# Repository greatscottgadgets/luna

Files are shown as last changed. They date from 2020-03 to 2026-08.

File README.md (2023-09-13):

# LUNA: an Amaranth HDL library for USB  

LUNA is a toolkit for working with USB using FPGA technology, providing gateware and software to enable USB applications.

Some things you can use LUNA for, currently:

- **Protocol analysis for Low-, Full-, or High- speed USB.** LUNA provides gateware that allow passive USB monitoring when combined with [Cynthion](https://github.com/greatscottgadgets/cynthion-hardware) and [Packetry](https://github.com/greatscottgadgets/packetry).
- **Creating your own Low-, Full-, High-, or (experimentally) Super- speed USB device.** LUNA provides a collection of Amaranth gateware that allows you to easily create USB devices in gateware, software, or a combination of the two.
- **Building USB functionality into a new or existing System-on-a-Chip (SoC).** LUNA is capable of generating custom peripherals targeting the common Wishbone bus; allowing it to easily be integrated into SoC designs; and the [luna-soc](https://github.com/greatscottgadgets/luna-soc) library provides simple automation for developing simple SoC designs.

Some things you'll be able to use LUNA for in the future:

- **Man-in-the-middle'ing USB communications.** The LUNA toolkit will be able to act
  as a *USB proxy*, transparently modifying USB data as it flows between a host and a device.
- **USB reverse engineering and security research.** The LUNA toolkit will serve as an ideal
  backend for tools like [Facedancer](https://github.com/usb-tools/facedancer); allowing easy
  emulation and rapid prototyping of compliant and non-compliant USB devices.

## Project Structure

This project is broken down into several directories:

* `luna` -- the primary LUNA python toolkit; generates gateware and provides USB functionality
  * `luna/gateware` -- the core gateware components for LUNA; and utilities for stitching them together
* `examples` -- simple LUNA-related examples; mostly gateware-targeted, currently
* `docs` -- sources for the LUNA Sphinx documentation
* `contrib` -- contributed/non-core components; such as udev rules
* `applets` -- pre-made gateware applications that provide useful functionality on their own (e.g., are more than examples)

## Project Documentation

LUNA's documentation is captured on [Read the Docs](https://luna.readthedocs.io/en/latest/). Raw documentation sources
are in the `docs` folder.

## Related Projects

* [Cynthion](https://github.com/greatscottgadgets/cynthion-hardware): an open source hardware USB test instrument
* [Apollo](https://github.com/greatscottgadgets/apollo): the firmware that runs on Cynthion's debug controller and which is responsible for configuring its FPGA
* [Saturn-V](https://github.com/greatscottgadgets/saturn-v): a DFU bootloader created for Cynthion
* [Packetry](https://github.com/greatscottgadgets/packetry): software for USB analysis
* [Facedancer](https://github.com/greatscottgadgets/facedancer): software to create USB devices in Python

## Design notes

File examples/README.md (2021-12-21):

# LUNA Examples

This folder contains simple example projects for LUNA, both for using LUNA as a specialized FPGA board, and for using the LUNA framework.

Included;

 * `blinky_verilog`: Simple example of how to program a LUNA board in Verilog.
 * `blinky`: A more standard blinky example, in Amaranth HDL.

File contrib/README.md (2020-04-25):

# Misc / 'Contributed' Files

This folder contains files that are not supported as part of the core LUNA project, but which may be useful to users anyway.

Contents:

 - `54-luna-uaccess.rules` -- _udev_ rules that grant users physically present at a machine access to LUNA devices. Recommended for most desktop Linux users.
 - `54-luna-plugdev.rules` -- _udev_ rules that grant users in the `plugdev` group access to LUNA devices. Recommended for systems where you'll be acccessing the toolsremotely; e.g. via SSH.

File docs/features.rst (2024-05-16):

================
Status & Support
================

.. role:: planned
.. role:: inprogress
.. role:: needstest
.. role:: complete

The LUNA library is a work in progress; but many of its features are usable enough for inclusion in your own designs.
More testing of our work -- and more feedback -- is always appreciated!

Support for Device Mode
-----------------------

.. list-table::
    :header-rows: 1
    :widths: 1 2 1

    * - Feature
      -
      - Status
    * - **USB Communications**
      - high-/full-speed with ``UTMI`` PHY
      - :needstest:`complete, needs testing`
    * -
      - high-/full-speed with ``ULPI`` PHY
      - :complete:`feature complete`
    * -
      - full-speed using raw gpio / pull resistors
      - :complete:`feature complete`
    * -
      - super-speed using PIPE PHY
      - :needstest:`basic support complete; still experimental`
    * -
      - super-speed using SerDes PHY
      - :inprogress:`in progress`
    * -
      - low speed, via ULPI/UTMI PHY
      - :planned:`untested`
    * -
      - low speed, using raw gpio / pull resistors
      - :planned:`unsupported, currently`
    * -
      -
      -
    * - **Control Transfers / Endpoints**
      - user-defined
      - :complete:`feature complete`
    * -
      - fully-gateware-implemented, with user vendor request handler support
      - :needstest:`complete, could use improvements`
    * -
      - CPU interface
      - :inprogress:`working; needs more interfaces & examples`
    * -
      -
      -
    * - **Bulk Transfers / Endpoints**
      - user-defined
      - :complete:`feature complete`
    * -
      - ``IN`` stream helpers
      - :complete:`feature complete`
    * -
      - ``OUT`` stream helpers
      - :complete:`feature complete`
    * -
      - CPU interface
      - :inprogress:`working; needs more interfaces & examples`
    * -
      -
      -
    * - **Interrupt Transfers / Endpoints**
      - user-defined
      - :complete:`feature complete`
    * -
      - status-to-host helper
      - :needstest:`complete, needs testing`
    * -
      - status-from-host helper
      - :planned:`planned`
    * -
      - CPU interface
      - :inprogress:`working; needs more interfaces & examples`
    * -
      -
      -
    * - **Isochronous Transfers / Endpoints**
      - user-defined
      - :planned:`planned`
    * -
      - ``IN`` transfer helpers
      - :needstest:`complete; needs examples and testing`
    * -
      - ``OUT`` transfer helpers
      - :planned:`planned`
    * -
      - CPU interface
      - :planned:`planned`
    * -
      -
      -
    * - **USB Analysis**
      - basic analysis
      - :inprogress:`basic analysis working, in progress`
    * -
      - full analysis support
      - :planned:`planned`

Support for Host Mode
-----------------------

The LUNA library currently does not provide any support for operating as a USB host; though the low-level USB
communications interfaces have been designed to allow for eventual host support. Host support is not currently
a priority, but contributions are welcome.

"Reference" Boards
------------------

The LUNA library is intended to work on any FPGA with sufficient fabric performance and resources; but testing is
only performed on a collection of reference boards.

.. list-table::
    :header-rows: 1
    :widths: 4 2 2 2

    * - Board
      - FPGA Family
      - PHY
      - Status
    * - `Cynthion <https://greatscottgadgets.com/cynthion/>`__
      - ECP5
      - ULPI x3 (USB3343)
      - :complete:`Fully Supported`
    * - OpenVizsla USB Analyzer
      - Spartan 6
      - ULPI (USB3343)
      - :complete:`Fully Supported`
    * - LambdaConcept ECPIX-5
      - ECP5
      - ULPI (USB3300), SerDes PHY
      - :complete:`High-Speed Fully Supported` / :inprogress:`Super-Speed In Progress`
    * - TinyFPGA Ex
      - ECP5
      - SerDes PHY
      - :planned:`Planned Super-Speed Device Mode`
    * - Logicbone
      - ECP5
      - SerDes PHY
      - :complete:`Full-Speed Fully Supported` / :inprogress:`Super-Speed In Progress`
    * - Daisho
      - Cyclone IV
      - PIPE (TUSB1310A)
      - :planned:`Planned Super-Speed Device Mode`
    * - PHYWhisperer-USB
      - Spartan 7
      - UTMI
      - :planned:`Planned Device Mode Support`
    * - LambdaConcept USB2Sniffer
      - Artix 7
      - ULPI x2 (USB3300)
      - :complete:`Fully Supported`
    * - OrangeCrab
      - ECP5
      - no hardware PHY
      - :complete:`Full-Speed/Device Mode Support`
    * - ULX3S
      - ECP5
      - no hardware PHY
      - :complete:`Full-Speed/Device Mode Support`
    * - Fomu PVT/Hacker
      - iCE40 UP
      - no hardware PHY
      - :complete:`Full-Speed/Device Mode Support`
    * - Fomu EVT3
      - iCE40 UP
      - no hardware PHY
      - :complete:`Full-Speed/Device Mode Support`
    * - iCEBreaker Bitsy
      - iCE40 UP
      - no hardware PHY
      - :complete:`Full-Speed/Device Mode Support`
    * - Glasgow
      - iCE40 HX
      - no hardware PHY
      - :planned:`Planned Full-Speed Support`
    * - TinyFPGA Bx
      - iCE40 LP
      - no hardware PHY
      - :complete:`Full-Speed/Device Mode Support`
    * - Digilent Nexys Video (SS with add-on board)
      - Artix 7
      - FMC for PIPE (TUSB1310A) add-on boards
      - :complete:`Super-Speed Fully Supported`
    * - Digilent Genesys2 (SS with add-on board)
      - Kintex 7
      - ULPI (TUSB1210), FMC for PIPE (TUSB1310A) add-on boards
      - :complete:`High/Super-Speed Fully Supported`

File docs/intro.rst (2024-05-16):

============
Introduction
============

    *Note: LUNA is still a work in progress; and while much of the technology is in a usable state,
    much of its feature-set is still being built. Consider LUNA an 'unstable' library, for the time being.*

Welcome to the LUNA project! LUNA is a full toolkit for working with USB using FPGA technology; and provides
gateware to enable USB applications.

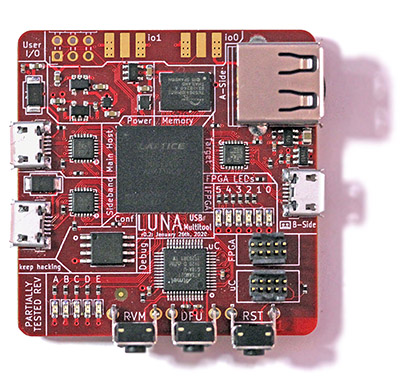
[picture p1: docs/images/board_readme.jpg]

..

Some things you can use LUNA for, currently:

- **Protocol analysis for Low, Full or High speed USB.** LUNA provides gateware that allow passive USB monitoring.
  When combined with the `Packetry <https://github.com/greatscottgadgets/packetry/>`__ USB protocol analysis
  application and suitable :ref:`hardware <features:"Reference" Boards>`, such as `Cynthion <https://greatscottgadgets.com/cynthion/>`__,
  it can be used as a full-featured USB analyzer.
- **Creating your own Low, Full or High speed USB device.** LUNA provides a collection of Amaranth gateware that
  allows you to easily create USB devices in gateware, software, or a combination of the two.
- **Building USB functionality into a new or existing System-on-a-Chip (SoC).** LUNA is capable of generating custom
  peripherals targeting the common Wishbone bus; allowing it to easily be integrated into SoC designs; and the
  `luna-soc <https://github.com/greatscottgadgets/luna-soc>`__ library provides simple automation for developing
  simple SoC designs.

Some things you'll be able to use LUNA for in the future:

- **Man-in-the-middle'ing USB communications.** LUNA will be able to act as a *USB proxy*, transparently
  modifying USB data as it flows between a host and a device.
- **USB reverse engineering and security research.** LUNA will serve as an ideal backend for tools like
  `Facedancer <https://github.com/usb-tools/facedancer>`__; allowing easy  emulation and rapid prototyping
  of compliant and non-compliant USB devices.

More details on these features are covered in `the source <https://github.com/greatscottgadgets/luna>`__, and in
the remainder of this documentation.

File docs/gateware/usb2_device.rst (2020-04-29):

============================
Core USB 2.0 Device Gateware
============================

The *LUNA* gateware library provides a flexible base *USB Device* model, which is designed to provide the basis
for creating both application-specific and general-purpose USB hardware.

USB devices are created using two core components:

* A :class:`USBDevice` instance, which provides hardware that handles low-level USB communications, and which is
  designed to be applicable to all devices; and
* One or more *endpoint interfaces*, which handle high-level USB communications -- and provide the logic
  the tailors the device to its intended application.

The ``USBDevice`` communicates with low-level transciever hardware via the FPGA-friendly *USB Transceiver*
*Macrocell Interface* (UTMI). Translators can be used to transparently adapt the FPGA interface to other
common bus formats; including the common ULPI low-pin-count variant of UTMI.

USB 2.0 architecture diagram

   The overall architecture of a LUNA USB 2.0 device, highlighting the ``USBDevice`` components, their
   connections to the *endpoint interfaces*, and optional *bus translator*.

Conceptual Components
---------------------

The ``USBDevice`` class contains the low-level communications hardware necessary to implement a USB device;
including hardware for maintaining device state, detecting events, reading data from the host, and generating
responses.

Token Detector
==============

The *Token Detector* detects *token packets* from the host; and is responsible for:

* Detecting *start of frame* packets, which are used to maintain consistent timing across USB devices.
* Detecting the start of USB *transactions*.
* Identifying the *device* and *endpoint* to which each transaction is addressed.

As each USB transaction starts with a token packet; it is implicitly the Token Detector's responsiblity
to notify endpoint interfaces of imminent incoming data (``OUT`` transactions) and requests for data (``IN``
transactions).

Handshake Detector
==================

The *Handshake Detector* detects *handshake packets* from the host; and is responsible for
identifying the host's response to packets from the device -- indicating whether the host
successfully received a packet sent from the device.

Data Packet Receiver
=====================

The *Data Packet Receiver* is responsible for receiving data packets from the device -- including
the payloads of both ``OUT`` and ``SETUP`` transactions -- and translating them to a simple data stream.

The Data Receiver handles error detection; and thus validates the checksums of each packet using the
Data CRC Unit.

Device State Manager
====================

The *Device State Manager* is responsible for storing global device state -- primarily, the
device's current *address* and *configuration*. The device state manager accepts changes to
the device's address/configuration from each endpoint interface; and automatically resets the
relevant parameters when a USB reset is received.

Handshake Generator
===================

The *Handshake Generator* provides a simple, strobe-based interface that allows endpoints to
easily emit handshake packets -- allowing the device to acknowledge packets (ACK), issue stalls
(STALL) , and to rate limit communications (NAK/NYET).

Data Packet Transmitter
=======================

The *Data Packet Generator* is responsible for generating outgoing USB packets from simple data
streams; including emitting data packet IDs, sending data, and appending data CRCs. This class
automatically appends the required data CRC-16s.

Data CRC Unit
=============

The *Data CRC Unit* is shared among the packet receiver and packet generator; and handles computing
the CRC-16 for USB data streams.

Interpacket Timer
=================

The *Interpacket Timer* is responsible for maintaining maximum and minimum interpacket delays; ensuring
that the device can correctly provide bus turnover times; and knows the window in which handshake packets
are expected to arrive.

Reset/Suspend Sequencer
=======================

The *Reset/Suspend Sequencer* is responsible for detecing USB reset and suspend events; and where applicable,
participating in the USB reset protocol's high-speed detection handshake.

The sequencer:

* Detects USB resets; and communicates to the Device State Manager that it should return the device to an
  un-addressed, un-configured state.
* Performs the *high speed detection handshake*, which allows the device to switch to High Speed operation;
  and thus is necessary for the device to operate at high speed.
* Manages the high-speed terminations; as part of the reset-handshake and suspend protocols.
* Detects the periods of inactivity that indicate the device is being suspended; and automatically disengages
  high-speed terminations while the device is in suspend.

``usb2.device`` Components
--------------------------

.. automodule :: luna.gateware.usb.usb2.device
  :members:
  :show-inheritance:

``usb2.packet`` Components
--------------------------

.. automodule :: luna.gateware.usb.usb2.packet
  :members:
  :show-inheritance:

``usb2.reset`` Components
--------------------------

.. automodule :: luna.gateware.usb.usb2.reset
  :members:
  :show-inheritance:

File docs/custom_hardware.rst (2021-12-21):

=========================
LUNA On Your Own Hardware
=========================

The LUNA stack is designed to be easy to use on your own FPGA hardware -- if you can already run Amaranth designs
on your board, all you'll need is to set up some I/O definitions and some clock domains.

The exact platform requirements depend on how you'll perform USB interfacing, and are detailed below.

High-Speed via a ULPI PHY
-------------------------

Using a ULPI PHY is relatively straightforward; and typically requires no hardware beyond the ULPI PHY. LUNA works with
both designs that receive their ``usb``-domain clocks from the PHY (typical) and designs that provide a 60MHz clock to
their PHY.

The following clock domains are required:

.. list-table::
    :header-rows: 1
    :widths: 1 1 5

    * - Domain Name
      - Frequency
      - Description
    * - ``usb``
      - 60 MHz
      - Core clock for the PHY's clock domain. *Can be provided to the FPGA by the PHY, or provided to the PHY by the FPGA.*
        *See below.*

An I/O resource with the following subsignals is required:

.. list-table::
    :header-rows: 1
    :widths: 1 1 1 6

    * - Subsignal Name
      - Width
      - Direction
      - Description
    * - ``clk``
      - 1
      - input *or* output
      - The ULPI bus clock. Should be configured as an input if the PHY is providing our clock
        (typical), or as an output if the FPGA will provide the clock to the PHY.
    * - ``data``
      - 8
      - bidirectional
      - The bidirectional data bus.
    * - ``dir``
      - 1
      - input
      - The ULPI *direction* signal.
    * - ``nxt``
      - 1
      - input
      - The ULPI *next* signal.
    * - ``stp``
      - 1
      - output
      - The ULPI *stop* signal.
    * - ``rst``
      - 1
      - output
      - The ULPI *reset* signal. The gateware asserts this signal when the PHY should be reset;
        if the PHY requires an active-low reset, this can be inverted with ``PinsN``.

An example resource might look like:

.. code-block:: python

    # Targeting the USB3300 PHY, which provides our clock.
    Resource("ulpi", 0,
            Subsignal("data",  Pins(data_sites,  dir="io")),
            Subsignal("clk",   Pins(clk_site,    dir="i" )),
            Subsignal("dir",   Pins(dir_site,    dir="i" )),
            Subsignal("nxt",   Pins(nxt_site,    dir="i" )),
            Subsignal("stp",   Pins(stp_site,    dir="o" )),
            Subsignal("rst",   Pins(reset_site,  dir="o" )),
            Attrs(IO_TYPE="LVCMOS33")
        )

Full-Speed using FPGA I/O
-------------------------

LUNA provides a *gateware PHY* that enables an FPGA to communicate at Full Speed using only FPGA 3V3 I/O
and a pull-up resistor. The FPGA must be able to provide stable 48 MHz and 12 MHz clocks.

The following clock domains are required:

.. list-table::
    :header-rows: 1
    :widths: 1 1 5

    * - Domain Name
      - Frequency
      - Description
    * - ``usb``
      - 12 MHz
      - Core clock for USB data. Ticks at the USB bitrate of 12MHz, and drives most of the USB logic.
    * - ``usb_io``
      - 48 MHz
      - Edge clock for the USB I/O. Used at the I/O boundary for clock recovery and NRZI encoding.

An I/O resource with the following subsignals is required:

.. list-table::
    :header-rows: 1
    :widths: 1 1 1 6

    * - Subsignal Name
      - Width
      - Direction
      - Description
    * - ``d_p``
      - 1
      - bidirectional
      - The raw USB D+ line; must be on a 3.3V logic bank.
    * - ``d_n``
      - 1
      - bidirectional
      - The raw USB D- line; must be on a 3.3V logic bank.
    * - ``pullup``
      - 1
      - output
      - Control for the USB pull-up resistor; should be connected to D+ via a 1.5k resistor.
    * - ``vbus_valid``
      - 1
      - input
      - *Optional*. If provided, this signal will be used for VBUS detection logic; should be asserted whenever
        VBUS is present. Many devices are "bus-powered" (receive their power from USB), and thus have no need
        for VBUS detection, in which case this signal can be omitted.

An example resource might look like:

.. code-block:: python

    Resource("usb", 0,
        Subsignal("d_p",    Pins("A4")),
        Subsignal("d_n",    Pins("A2")),
        Subsignal("pullup", Pins("D5", dir="o")),
        Attrs(IO_STANDARD="SB_LVCMOS"),
    ),

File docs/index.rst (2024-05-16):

==========================
LUNA: USB Gateware Library
==========================

This is the documentation for the LUNA USB Gateware Library.

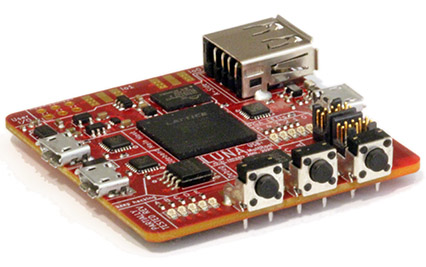
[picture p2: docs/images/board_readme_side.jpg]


Much like the LUNA gateware this documentation is a work in progress.
Contributions are always appreciated.

.. toctree::
   :maxdepth: 2
   :caption: Contents:

   intro
   features
   getting_started
   custom_hardware
   gateware/usb2_device
   gateware/endpoint

Generated indices
==================

* :ref:`genindex`
* :ref:`modindex`
* :ref:`search`

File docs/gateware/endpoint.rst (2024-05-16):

============================
Gateware Endpoint Interfaces
============================

The LUNA architecture separates gateware into two distinct groups: the *core device*, responsible for the
low-level communications common to all devices, and *endpoint interfaces*, which perform high-level communications,
and which are often responsible for tailoring each device for its intended application:



Every useful LUNA device features at least one endpoint interface capable of at least handling enumeration. Many
devices will provide multiple endpoint interfaces -- often one for each endpoint -- but this is not a requirement.
Incoming token, data, and handshake packets are routed to all endpoint interfaces; it is up to each endpoint interface
to decide which packets to respond to.

    *Note: terms like "interface" are overloaded: the single term "interface" can refer both to hardware interfaces
    and to the USB concept of an Interface. The "interface" in "endpoint interface" is an instance of the former;
    they are conceptually distinct from USB interfaces. To reduce conflation, we'll use the full phrase "endpoint
    interface" in this document.*

As a single endpoint interface may handle packets for multiple endpoints; it is entirely possible to have a device
that talks on multiple endpoints, but which uses only one endpoint interface.

Exclusivity
-----------

A LUNA ``USBDevice`` performs no arbitration -- if two endpoint interfaces attempt to transmit at the same time, the
result is undefined; and often will result in undesirable output. Accordingly, it's important to ensure a "clear
delineation of responsibility" across endpoint interfaces. This is often accomplished by ensuring only one endpoint
interface handles a given endpoint or request type.

``usb2.endpoint`` Components
----------------------------

.. automodule :: luna.gateware.usb.usb2.endpoint
  :members:
  :show-inheritance:

Provided Endpoint Interfaces
----------------------------

The LUNA library ships with a few provided endpoint interfaces. These include:

- The :class:`USBControlEndpoint`, which provides gateware that facilitates handling USB control requests.
  To handle requests via this endpoint, the user attaches one or more *request handlers interfaces*; which
  are documented in their own section.
- The `*FIFOInterface <https://luna-soc.readthedocs.io/en/latest/eptri.html>`__ classes, which implement simple,
  FIFO-based software interfaces. These lightweight interfaces are meant to allow simple CPU control over one or
  more endpoints. These are based off of the ValentyUSB ``eptri`` interface; and will eventually be
  binary-compatible with existing ``eptri`` code.

``usb2.control`` Components
---------------------------

.. automodule :: luna.gateware.usb.usb2.control
  :members:
  :show-inheritance:

``usb2.interfaces.eptri`` Components
------------------------------------

See the `luna-soc documentation <https://luna-soc.readthedocs.io/en/latest/api_docs/luna_soc.gateware.csr.usb2.interfaces.html>`__.

Bulk Endpoint Helpers / ``usb2.endpoints.stream`` Components
------------------------------------------------------------

.. automodule :: luna.gateware.usb.usb2.endpoints.stream
  :members:
  :show-inheritance:

Interrupt Endpoint Helpers / ``usb2.endpoints.status`` Components
-----------------------------------------------------------------

.. automodule :: luna.gateware.usb.usb2.endpoints.status
  :members:
  :show-inheritance:

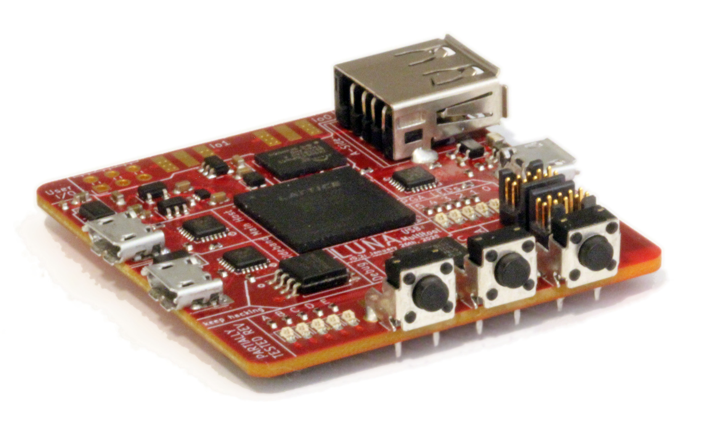
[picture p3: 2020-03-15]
docs/images/board_side.jpg

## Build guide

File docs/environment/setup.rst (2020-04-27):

==============================
Setting up a Build Environment
==============================

This guide highlights the installation / setup process for the ``luna``
gateware library. It focuses on getting the Python module (and
prerequisites) up and running.

Prerequisites
-------------

-  Python 3.7, or later.
-  A working FPGA toolchain. We only officially support a toolchain
   composed of the `Project
   Trellis <https://github.com/SymbiFlow/prjtrellis>`__ ECP5 tools, the
   `yosys <https://github.com/YosysHQ/yosys>`__ synthesis suite, and the
   `NextPNR <https://github.com/YosysHQ/nextpnr>`__ place-and-route
   tool. All of these tools must be built from ``master``.
-  A working installation of
   `nMigen <https://github.com/nmigen/nmigen>`__. Note that only the
   official toolchain from `@nmigen <https://github.com/nmigen>` is
   supported; the `@m-labs <https://github.com/m-labs>` derivative is
   not.

Installation
------------

Currently, the ``luna`` library is considered a “work-in-progress”; and
thus it’s assumed you’ll want to use a local copy of ``luna`` for
development.

The easiest way to set this up is to install the distribution in-place.
From the root of the repository:

.. code:: sh

   # Pull down our requirements.
   pip3 install -r requirements.txt --user

   # Install an "in-place" development copy.
   python3 setup.py develop --user

Testing
-------

The easiest way to test your installation is to run one of the test
applets. These applets are just Python scripts that construct and
program gateware using nMigen; so they can be run like any other script:

.. code:: sh

   # With a LUNA board connected; we can run the full test.
   python3 applets/interactive-test.py

   # Without a board connected, we can still exercise the toolchain.
   python3 applets/interactive-test.py --dry-run

The ``luna-dev`` utility.
-------------------------

The ``luna`` distribution ships with a utility that can be used to
perform various simple functions useful in development; including simple
JTAG operations, SVF playback, manipulating the board’s flash, and debug
comms.

.. code:: sh

   $ luna-dev
   usage: luna-dev [-h] command: [[argument]] [[value]]

   Utility for LUNA development via an onboard Debug Controller.

   positional arguments:
     command:    info       -- Prints information about any connected LUNA-compatible boards
                 configure  -- Uploads a bitstream to the device's FPGA over JTAG.
                 erase      -- Clears the attached board's configuration flash.
                 program    -- Programs the target bitstream onto the attached FPGA.
                 jtag-scan  -- Prints information about devices on the onboard JTAG chain.
                 flash-scan -- Attempts to detect any attached configuration flashes.
                 svf        -- Plays a given SVF file over JTAG.
                 spi        -- Sends the given list of bytes over debug-SPI, and returns the response.
                 spi-inv    -- Sends the given list of bytes over SPI with inverted CS.
                 spi-reg    -- Reads or writes to a provided register over the debug-SPI.
     [argument]  the argument to the given command; often a filename
     [value]     the value to a register write command

To have easy access to the ``luna-dev`` command, you’ll need to ensure
that your python binary directory is in your ``PATH``. For macOS/Linux,
this often means adding ``~/.local/bin`` to your ``PATH``.

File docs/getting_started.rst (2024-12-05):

===============
Getting Started
===============

Setting up a Build Environment
~~~~~~~~~~~~~~~~~~~~~~~~~~~~~~

This guide highlights the installation / setup process for the LUNA
gateware library. It focuses on getting the Python module (and
prerequisites) up and running.

Prerequisites
-------------

-  Python 3.9, or later.
-  A working FPGA toolchain. We only officially support a toolchain
   composed of the `Project
   Trellis <https://github.com/YosysHQ/prjtrellis>`__ ECP5 tools, the
   `yosys <https://github.com/YosysHQ/yosys>`__ synthesis suite, and the
   `NextPNR <https://github.com/YosysHQ/nextpnr>`__ place-and-route
   tool. You can obtain the latest binary distribution of this
   software from the `oss-cad-suite-build <https://github.com/YosysHQ/oss-cad-suite-build>`__
   project.
-  A working installation of
   `Amaranth HDL <https://github.com/amaranth-lang/amaranth>`__.

Installation
------------

Currently, the LUNA library is considered a “work-in-progress”; and
thus it’s assumed you’ll want to use a local copy of LUNA for
development.

.. code:: sh

    # clone the LUNA repository
    git clone https://github.com/greatscottgadgets/luna.git

The easiest way to set this up is to install the distribution in your working environment.
From the root of the repository:

.. code:: sh

   # Install a copy of our local tools.
   pip install .

   # Alternatively: install all dependencies,
   # including optional development packages (required for running applets and examples).
   pip install .[dev]

If you want to install LUNA to your machine globally (not recommended), you can do so
using the following single command:

.. code:: sh

   # Create a LUNA package, and install it.
   pip install . --user

Testing
-------

The easiest way to test your installation is to build one of the test
applets. These applets are just Python scripts that construct and
program gateware using Amaranth HDL; so they can be run like any other script:

.. code:: sh

   # With GSG or self-built Cynthion hardware connected; we can test both our
   # installation and the attached hardware.
   python applets/bulk_speed_test.py

   # Without hardware connected, we'll only build the applet, to exercise
   # our toolchain.
   python applets/bulk_speed_test.py --dry-run

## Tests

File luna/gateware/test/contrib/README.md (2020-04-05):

# test.contrib

This folder contains files adopted from other (license-compatible) sources.
In particular, code is repurposed from Antmicro's usb-test-suite.

See individual files for their licenses.

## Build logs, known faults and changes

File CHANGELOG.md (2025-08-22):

# Changelog

All notable changes to this project will be documented in this file.

The format is based on [Keep a Changelog](https://keepachangelog.com/en/1.1.0/),
and this project adheres to [Semantic Versioning](https://semver.org/spec/v2.0.0.html).

<!--
## [Unreleased]
-->

## [0.2.3] - 2025-08-22
### Fixed
* `luna.full_devices.USBSerialDevice` fails with Windows host.

## [0.2.2] - 2025-08-01
### Added
* Support for non-contiguous descriptor indices without requiring `avoid_blockram`.
* `StreamSerializer` can now send descriptors with more than 64 bytes of content.  (tx povauboin!)

### Changed
* Deprecate `blacklist` in favor of `skiplist` in `StandardRequestHandler` method: `add_standard_request_handlers()`.

### Fixed
* `handle_write_register_write_request` is no longer limited to a 7 bit value.

## [0.2.1] - 2025-06-10
### Added
* Add support for streaming USB 2.0 Isochronous Endpoints.

## [0.2.0] - 2025-02-25
### Added
* Support for Amaranth 0.5.x
### Changed
* Use `amaranth.lib.memory.Memory` instead of `amaranth.hdl.Memory`.
### Removed
* The `synchronize` helper function. Use `amaranth.lib.cdc.FFSynchronizer` instead.
* Old examples and components that used the `debug_spi` interface.
### Security
* Bump jinja2 from 3.1.4 to 3.1.5

## [0.1.3] - 2024-12-18
### Added
* Support for yowasp when yosys is unavailable.
### Changed
* Dropped support for Python 3.8

## [0.1.2] - 2024-09-19
### Changed
* Use `debugger.force_fpga_online()` instead of `programmer.unconfigure()` to take FPGA offline.
* Remove unused/out-of-date imports from PIPE PHY example.

## [0.1.1] - 2024-07-05
### Added
- New `LUNAApolloPlatform` property: `apollo_gateware_phy`
- Support for `ClearFeature(ENDPOINT_HALT)`
### Changed
- Remove Cynthion VID/PIDs from udev rules

## [0.1.0] - 2024-06-12
### Added
- Initial release

[Unreleased]: https://github.com/greatscottgadgets/luna/compare/0.2.3...HEAD
[0.2.3]: https://github.com/greatscottgadgets/luna/compare/0.2.2...0.2.3
[0.2.2]: https://github.com/greatscottgadgets/luna/compare/0.2.1...0.2.2
[0.2.1]: https://github.com/greatscottgadgets/luna/compare/0.2.0...0.2.1
[0.2.0]: https://github.com/greatscottgadgets/luna/compare/0.1.3...0.2.0
[0.1.3]: https://github.com/greatscottgadgets/luna/compare/0.1.2...0.1.3
[0.1.2]: https://github.com/greatscottgadgets/luna/compare/0.1.1...0.1.2
[0.1.1]: https://github.com/greatscottgadgets/luna/compare/0.1.0...0.1.1
[0.1.0]: https://github.com/greatscottgadgets/luna/releases/tag/0.1.0

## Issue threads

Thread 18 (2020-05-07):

design an r0.3

ktemkin, 2020-05-07:
Some potential changes for r0.3:

- [x] Re-spec 3V3 regulator to reduce ripple; or at the least, remove its bypass capacitor.
- [x] Improve grounding / thermal connections for the USB PHYs.
- [x] Potentially switch between the active-high and active-low versions of our load switches / switch the load configuration to reduce leakage.
- [x] Replace the USB PHY pull-up resistors with pull-down ones.
- [x] Replace the 60MHz oscillator with the cheaper / lower-jitter `SIT1602BC-73-33E-60.000000E`.
- [x] Re-evaluate availability and see if switching the 1V1 regulator to its larger package (`EF` vs `EE`) makes sense.
- [x] Clean up redundant input caps (C6, C40, C47) on 3V3 regulator (U3).
- [x] Remove redundant C45.
- [x] Change R17, R19, R21 to 5%.
- [x] Add TC2030-NL footprint for SWD.
- [x] Improve pin 1 marking of oscillator Y1 footprint.
- [x] Add "Substitution" BOM field ("any equivalent" for most passives).
- [x] Select LED components and matching series resistors.
- [x] Move LED silkscreen labels closer to LEDs.
- [x] Connect `PROGRAM_N` to a nearby 3V3 FPGA I/O to allow for easier Debug Controller-less operation.
- [x] Potentially swap the SAMD21 with a SAMD11, for cost reduction.
- [x] Potentially move to USB-C connectors, instead of microUSB.

ktemkin, 2020-05-15:
@mossmann assigning you `r0.3`-related tasks, for now. Feel free to re-assign. :)

mossmann, 2020-05-21:
Work in progress is in this branch: https://github.com/mossmann/luna/tree/r0.3

mossmann, 2020-05-21:
I've removed bypass capacitor C52 from the +3V3 regulator at least as a temporary measure. I will likely replace the regulator entirely after some testing.

ktemkin, 2020-08-07:
Added one more bullet:

- Connect PROGRAM_N to a nearby 3V3 FPGA I/O to allow for easier Debug Controller-less operation.

This will allow the FPGA to trigger its own reconfiguration.

mossmann, 2020-12-08:
I resolved the load switch issue primarily by reducing the resistance of the pull-up and pull-down resistors on the load switch enable pins.

Closed 2021-01-19.

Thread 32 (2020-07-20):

Incorrect bInterfaceProtocol value for ACM Serial

BracketMaster, 2020-07-20:
I tried the ACMSerial example on my TinyFPGA.
I'm using a Mac.
Lsusb shows the USB device, but the MacOS kernel
neglects to mount it as an ACM device.

I found that Luna sets the ``bInterfaceProtocol`` to ``2``.
https://github.com/greatscottgadgets/luna/blob/master/luna/gateware/usb/devices/acm.py#L107

TinyFPGA USB-Serial core which successfully mounts on MacOS sets
that value to ``0``.
https://github.com/davidthings/tinyfpga_bx_usbserial/blob/master/usb/usb_serial_ctrl_ep.v#L371

According the the 1999 ACD CDC [USB specification](https://cscott.net/usb_dev/data/devclass/usbcdc11.pdf)
Section 4.4 page 30,, 0x02 is not implemented and 0x00 is the correct value.

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

The ACM example still works on Linux since the Linux ACM driver
is more forgiving. But this is still an issue none the less.

I can open a pull request to fix this.

ktemkin, 2020-07-27:
Thanks for reporting this -- it looks a lot like I typo'd and inserted a `0x02` when I meant `0x01`. Testing stuff out on macOS now and will report back. :)

BracketMaster, 2020-07-27:
Haha. No probs.
Also, MacOS wouldn't allow me to write to the device with screen.
I was however able to write to the device directly with PyUSB...

Which brings me to my next comment. Perhaps it might make sense to
include a PyUSB serial demo in the same folder as the ACMSerial demo
python code.

ktemkin, 2020-07-27:
MacOS seems happy with the technically-correct value of `0x01`. About to test on Windows.

> Also, MacOS wouldn't allow me to write to the device with screen.
> I was however able to write to the device directly with PyUSB...

There was another bug that I think was triggering this behavior (macOS was interleaving control request transactions with its IN tokens; and a bug in handling that caused the IN endpoint to get stalled). That's fixed in 087ad9c2376658ab7e82d46f4f010e77ff55d3c1, and `dterm` seems happy to work with the terminal.

I'll try screen after I try Windows to verify. :)

Closed 2020-07-27.

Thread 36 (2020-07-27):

Building eptri demo fails

kgugala, 2020-07-27:
When I tried to build the eptri demo I got bunch of missing type errors - `error: unknown type name 'uint8_t'`

adding `#include <stdint.h>` to `eptri_example.c` solves the above, but still i get bunch of implicit declarations warnings:

```
make                                                                                                                                          
riscv64-unknown-elf-gcc -march=rv32i -mabi=ilp32 -g -Os -Wall -Werror -Tsoc.ld -Triscv_standalone.ld  -nostdlib start.S eptri_example.c -o eptri_example.elf
eptri_example.c: In function 'print_char':
eptri_example.c:119:9: error: implicit declaration of function 'uart_tx_rdy_read' [-Werror=implicit-function-declaration]
  while(!uart_tx_rdy_read());
         ^~~~~~~~~~~~~~~~
eptri_example.c:120:2: error: implicit declaration of function 'uart_tx_data_write' [-Werror=implicit-function-declaration]
  uart_tx_data_write(c);
  ^~~~~~~~~~~~~~~~~~
eptri_example.c: In function 'read_setup_request':
eptri_example.c:167:10: error: implicit declaration of function 'setup_have_read' [-Werror=implicit-function-declaration]
   while(!setup_have_read());
          ^~~~~~~~~~~~~~~
eptri_example.c:170:18: error: implicit declaration of function 'setup_data_read' [-Werror=implicit-function-declaration]
   uint8_t byte = setup_data_read();
^~~~~~~~~~~~~~~
eptri_example.c: In function 'send_packet':                                   
eptri_example.c:187:2: error: implicit declaration of function 'in_ep_reset_write' [-Werror=implicit-function-declaration]
  in_ep_reset_write(1);
  ^~~~~~~~~~~~~~~~~
eptri_example.c:191:3: error: implicit declaration of function 'in_ep_data_write' [-Werror=implicit-function-declaration]
   in_ep_data_write(*buffer);
   ^~~~~~~~~~~~~~~~
( ... )
```

disabling `-Werror` ends up in undefined reference linker errors. Looks like some code is missing here (or is not generated before the example is built)

ktemkin, 2020-07-27:
Sounds like something changed in one of the upstreams; probably.  I'll check it out soon.

kgugala, 2020-09-16:
@ktemkin did you have a chance to take a look at this?

ktemkin, 2020-09-23:
I haven't come back around to looking at it; mostly because I've been laser focused on other things. I can take a look sometime this or next week, though. Poke me if I don't. :)

ktemkin, 2020-09-24:
Just tested with the environment I already had installed without issue; it's using:

```
minerva => 0.1
nmigen-soc => 0.1.dev30+g425692a
lambdasoc =>  0.1.dev21+g95a97de
```

I'm guessing upgrading one of those python packages is going to break things -- trying that now. :)

ktemkin, 2020-09-24:
Hmm; even after upgrading everything to its latest, I'm still not having issues:

```
minerva => 0.1 [but now installed from master]
nmigen-soc => 0.1.dev43+gecfad4d
lambdasoc =>  0.1.dev25+g7381b47
riscv64-unknown-elf-gcc => 9.2.0
riscv64-unknown-elf-newlib => 3.3.0
```

I'm particularly confused in that you're winding up with no `stdint.h` include, as `simplesoc` should always include that in the header it generates:

https://github.com/greatscottgadgets/luna/blob/master/luna/gateware/soc/simplesoc.py#L420

Some things that might be helpful in debugging:

1. What steps are you running to build? The simplest way is probably just to run `make program` in the demo folder.
2. Can you attach the `resources.h` and `soc.ld` that are generated by these build steps?

kgugala, 2020-11-04:
looks like `nmigen-stdio` was missing in my setup. The build process was actually showing that in the log, but did not stop on missing dependency. This ended up with empty `resources.h` and in the end the reported error. Adding `nmigen-stdio` to requirements.txt solves the problem

antoinevg, 2024-01-04:
eptri example code has moved to the Cynthion repo: https://github.com/greatscottgadgets/cynthion/

Closed 2024-01-04.

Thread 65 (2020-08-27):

Analyzer: Implement (PS)RAM buffering

ktemkin, 2020-08-27:
Currently, the analyzer uses block ram for buffering, which leads it to overrun very, very quickly. We should instead buffer the data in (PS)RAM, so we can have a good buffer depth.

MartinLoeper, 2021-06-14:
@ktemkin I am currently trying to read data from a HOST <-> Printer connection with LUNA instead of the USBProxy project.

Everything works well so far until the board goes into overrun state and I have to re-build and upload the applet again.
I also noticed that I have to wait with plugging the printer in until I start to read from the analyzer. Otherwise, the buffer overruns immediately after the applet starts to run.
Is it possible to somehow reset the analyzer state?

I read your comments about the [DRAM buffer support](https://github.com/greatscottgadgets/luna/blob/5d983e1ed82f6a7f14a0509ba9541a0c72c43f7f/luna/gateware/usb/analyzer.py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) and I really hope this feature gets attention over the next months.
That would allow us to test a LUNA device in the field, reading data from a POS <-> printer connection.

As always, thanks for the amazing work!

martinling, 2024-02-13:
The analyzer gateware has moved to the Cynthion repository; this issue is now tracked at https://github.com/greatscottgadgets/cynthion/issues/51.

Closed 2024-02-13.

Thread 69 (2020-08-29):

Rose/Fell still not being DomainRenamed correctly? (SyncSerialILA not working reliably in other domains)

miek, 2020-08-29:
I've been trying to use the `SyncSerialILA` in non-sync domains and have been having issues with it either returning all zeroes, or random garbage. I can reliably reproduce that by modifying the `basic_ila_fast_domain` example to run in the `usb` domain.

I tried setting up the `SyncSerialILA`'s SPI interface to output a fixed word to exclude any issues with the ILA itself and I was still getting zeros out. I eventually narrowed it down to no edges occuring on the `SPIDeviceInterface`'s `output_edge` (by routing that out to one of the user IOs and watching it on the scope while apollo did the download).

If I modify the `Rose`/`Fell` calls in `spi_edge_detectors` to use `domain="usb"` then everything seems to work correctly. This was supposed to be fixed by #30 but maybe there's some other corner case happening here? I don't know how to inspect the nMigen elaboration process well enough to debug that further.

(Also here's the IRC discussion that led to the PR above: https://freenode.irclog.whitequark.org/nmigen/2020-07-12#27492949;)

miek, 2024-05-23:
Uses of `Rose`/`Fell` were removed in #231

Closed 2024-05-23.

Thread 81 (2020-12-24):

(Fomu) examples/soc/: "nmigen.build.res.ResourceError: Resource uart#0 does not exist"

tcal-x, 2020-12-24:
This may well be a user error, but this is what I attempted:

With LUNA_PLATFORM=luna.gateware.platform.fomu:FomuPVT

In luna/examples/soc/hello/

```
$ python3 -m hello_world_soc
module: luna.gateware.platform.fomu  name: FomuPVT
INFO    | __init__    | Building and uploading gateware to attached Fomu PVT/Production...
INFO    | simplesoc   | Physical address allocations:
INFO    | simplesoc   |     00000000-00001000: <luna.gateware.soc.memory.WishboneROM object at 0x7f026399c5b0>
INFO    | simplesoc   |     00001000-00002000: <luna.gateware.soc.memory.WishboneRAM object at 0x7f026399c910>
INFO    | simplesoc   |     00002000-00002004: (rec uart_divisor r_data r_stb w_data w_stb)
INFO    | simplesoc   |     00002004-00002008: (rec uart_rx_data r_data r_stb)
INFO    | simplesoc   |     00002008-0000200c: (rec uart_rx_rdy r_data r_stb)
INFO    | simplesoc   |     0000200c-00002010: (rec uart_rx_err r_data r_stb)
INFO    | simplesoc   |     00002010-00002014: (rec uart_tx_data w_data w_stb)
INFO    | simplesoc   |     00002014-00002018: (rec uart_tx_rdy r_data r_stb)
INFO    | simplesoc   |     00002020-00002024: (rec uart_ev_status r_data r_stb)
INFO    | simplesoc   |     00002024-00002028: (rec uart_ev_pending r_data r_stb w_data w_stb)
INFO    | simplesoc   |     00002028-0000202c: (rec uart_ev_enable r_data r_stb w_data w_stb)
INFO    | simplesoc   |     00002040-00002044: (rec timer_reload r_data r_stb w_data w_stb)
INFO    | simplesoc   |     00002044-00002048: (rec timer_en r_data r_stb w_data w_stb)
INFO    | simplesoc   |     00002048-0000204c: (rec timer_ctr r_data r_stb w_data w_stb)
INFO    | simplesoc   |     00002050-00002054: (rec timer_ev_status r_data r_stb)
INFO    | simplesoc   |     00002054-00002058: (rec timer_ev_pending r_data r_stb w_data w_stb)
INFO    | simplesoc   |     00002058-0000205c: (rec timer_ev_enable r_data r_stb w_data w_stb)
INFO    | simplesoc   |     00002060-00002064: (rec leds_output r_data r_stb w_data w_stb)
INFO    | simplesoc   |
INFO    | simplesoc   | IRQ allocations:
INFO    | simplesoc   |     0: uart
INFO    | simplesoc   |     1: timer
INFO    | simplesoc   |
INFO    | simplesoc   |
Traceback (most recent call last):
  File "/usr/lib/python3.8/runpy.py", line 194, in _run_module_as_main
    return _run_code(code, main_globals, None,
  File "/usr/lib/python3.8/runpy.py", line 87, in _run_code
    exec(code, run_globals)
  File "/home/tim/greatscottgadgets/luna/examples/soc/hello/hello_world_soc.py", line 103, in <module>
    top_level_cli(design, cli_soc=design.soc)
  File "/home/tim/greatscottgadgets/luna/luna/__init__.py", line 140, in top_level_cli
    products = platform.build(fragment,
  File "/home/tim/icebreaker/icebreaker-nmigen-examples/env/src/nmigen/nmigen/build/plat.py", line 95, in build
    plan = self.prepare(elaboratable, name, **kwargs)
  File "/home/tim/icebreaker/icebreaker-nmigen-examples/env/src/nmigen/nmigen/build/plat.py", line 135, in prepare
    fragment = Fragment.get(elaboratable, self)
  File "/home/tim/icebreaker/icebreaker-nmigen-examples/env/src/nmigen/nmigen/hdl/ir.py", line 39, in get
    obj = obj.elaborate(platform)
  File "/home/tim/greatscottgadgets/luna/examples/soc/hello/hello_world_soc.py", line 92, in elaborate
    uart_io = platform.request("uart", 0)
  File "/home/tim/icebreaker/icebreaker-nmigen-examples/env/src/nmigen/nmigen/build/res.py", line 62, in request
    resource = self.lookup(name, number)
  File "/home/tim/icebreaker/icebreaker-nmigen-examples/env/src/nmigen/nmigen/build/res.py", line 57, in lookup
    raise ResourceError("Resource {}#{} does not exist"
nmigen.build.res.ResourceError: Resource uart#0 does not exist
```

ktemkin, 2021-01-06:
Oh! I think when we spoke earlier I didn't get that you were using some of the SoC examples. _Those_ don't currently work on `fomu`; because the SoC example chosen implements a hardware UART, rather than a virtual one.

If you're trying to use this with a _virtual_ serial device, that'd require implementing a simple SoC peripheral that, in turn, interfaces with LUNA's simple ACM virtual-serial, as here:

https://github.com/greatscottgadgets/luna/blob/master/examples/usb/acm_serial.py

ktemkin, 2021-01-06:
A (more complex) example of a peripheral is provided here:

https://github.com/greatscottgadgets/luna/blob/master/luna/gateware/usb/usb2/interfaces/eptri.py

You'd theoretically need to wrap LUNA's `USBSerialDevice` with a Peripheral, and then add e.g. a CSR (register) you can use to send data. I think that'd be a super interesting example -- feel free to open a feature request. :)

ktemkin, 2021-01-06:
I'm closing this since it's not technically a bug; I'd love to have this referenced in a new feature request, though, if you're willing to write one. :)

mithro, 2021-01-07:
@ktemkin - I think @tcal-x wants to use the LUNA core to handle the USB serial side and LiteX to provide the CSR peripherals. I /think/ the best way is to set up LUNA to provide a byte-FIFO like interface similar to what the FTDI ICs provide, then connect that to the LiteX byte UART peripheral which would normally talk to something like the FTDI IC? Does that make sense?

mithro, 2021-01-07:
My poor attempt at doing a diagram is shown at https://docs.google.com/drawings/d/1JMEMoRK5CP7TDy4U9-tuYUZqEjzRmwVNJWENpQxgR9g/edit
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

tcal-x, 2021-01-07:
Thanks @ktemkin , yes we chatted a bit on discord (1bitsquared).   So yes, things are working as expected, not a bug.  I think I did have success with the acm\_serial.py design.   Also, loopback.py didn't meet timing with the default pnr seed, but did meet timing with `--seed 198`.

I do have a working solution on Fomu with valentyusb and I think tinyusb, hooking into the uart / putc / printf stack (I hope that makes sense, I'm still figuring things out).   But I'd love to get to the same point with Luna too.   I'm not sure which if any pieces are missing.

Closed 2021-01-06.

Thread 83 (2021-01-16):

Setup: lambdasoc/software/bios/3rdparty/compiler-rt git repository has moved

rwhitby, 2021-01-16:
This is a lambdasoc-bios issue (and it has been reported there), but notifying here as well as it affects the Luna setup flow.

See https://github.com/lambdaconcept/lambdasoc-bios/pull/1 for the fix.

antoinevg, 2024-01-04:
Fixed in #213

Closed 2024-01-04.

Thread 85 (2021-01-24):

Failure while following 'getting started' instructions

mubes, 2021-01-24:
Hi,
This one is probably sticky fingers, but following the instructions at https://luna.readthedocs.io/en/latest/getting_started.html at the point where the dry-run tests are conducted, I get the following error;

```
~/Builds/luna$ python3 applets/interactive-test.py --dry-run
WARNING | __init__    | Couldn't auto-detect connected platform. Assuming LUNA r0.2.
INFO    | __init__    | Building for LUNA r0.2...
Traceback (most recent call last):
  File "applets/interactive-test.py", line 400, in <module>
    tester = top_level_cli(InteractiveSelftest)
  File "/home/dmarples/Builds/luna/luna/__init__.py", line 144, in top_level_cli
    products = platform.build(fragment,
  File "/home/dmarples/Builds/luna/src/nmigen/nmigen/build/plat.py", line 95, in build
    plan = self.prepare(elaboratable, name, **kwargs)
  File "/home/dmarples/Builds/luna/src/nmigen/nmigen/build/plat.py", line 154, in prepare
    add_pin_fragment(pin, self.get_input_output(pin, port, attrs, invert))
  File "/home/dmarples/Builds/luna/src/nmigen/nmigen/vendor/lattice_ecp5.py", line 607, in get_input_output
    i_T=t[bit],
  File "/home/dmarples/Builds/luna/src/nmigen/nmigen/hdl/ast.py", line 261, in __getitem__
    raise IndexError(f"Index {key} is out of bounds for a {n}-bit value")
IndexError: Index 1 is out of bounds for a 1-bit value
~/Builds/luna$
```
...am I doing something dumb?

mubes, 2021-01-24:
actually, I seem to get this problem while trying to build any of the examples, e.g. `python3 acm_serial.py` or `python3 stress_test_device.py`.

mubes, 2021-01-24:
Problem seems to relate to recent changes in nmigen. Replicated by Greg Davill.

ktemkin, 2021-01-25:
Looks like this is a bug in current nmigen/master. I've submitted a PR over there fixing it: https://github.com/nmigen/nmigen/pull/582/files :)

mubes, 2021-01-25:
Yep, fixes it for me. Ta!
Not sure what your protocol is for ending issues? I'll leave it open in case you want to track-to-fix upstream.

Closed 2021-02-03.

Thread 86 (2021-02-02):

Enumeration trouble, part 1

jboone, 2021-02-02:
I'm having trouble with a long USB 2.0 configuration descriptor -- 75 bytes.

Initially, I was seeing my Linux host complaining in `dmesg` about being unable to read the descriptor, after I'd added another interface with two alternate settings. Here's how the problematic descriptor looks:

```python3
with descriptors.DeviceDescriptor() as d:
    d.idVendor  = 0x16d0
    d.idProduct = 0x0f3b
    d.iManufacturer = "ShareBrained"
    d.iProduct      = "Tedium X8"
    d.iSerialNumber = "deadbeef"
    d.bNumConfigurations = 1

with descriptors.ConfigurationDescriptor() as c:

    with c.InterfaceDescriptor() as i:
        i.bInterfaceNumber = 0

        with i.EndpointDescriptor() as e:
            e.bEndpointAddress = USBDirection.IN.to_endpoint_address(1)
            e.wMaxPacketSize   = 64
            e.bmAttributes     = USBTransferType.INTERRUPT
            e.bInterval        = 4

    with c.InterfaceDescriptor() as i:
        i.bInterfaceNumber = 1
        i.bAlternateSetting = 0

    with c.InterfaceDescriptor() as i:
        i.bInterfaceNumber = 1
        i.bAlternateSetting = 1

        with i.EndpointDescriptor() as e:
            e.bEndpointAddress = USBDirection.IN.to_endpoint_address(2)
            e.wMaxPacketSize   = (1 << 11) | 24
            e.bmAttributes     = USBTransferType.ISOCHRONOUS
            e.bInterval        = 1

    with c.InterfaceDescriptor() as i:
        i.bInterfaceNumber = 2
        i.bAlternateSetting = 0

    with c.InterfaceDescriptor() as i:
        i.bInterfaceNumber = 2
        i.bAlternateSetting = 1

        with i.EndpointDescriptor() as e:
            e.bEndpointAddress = USBDirection.OUT.to_endpoint_address(3)
            e.wMaxPacketSize   = (1 << 11) | 24
            e.bmAttributes     = USBTransferType.ISOCHRONOUS
            e.bInterval        = 1
```

I built a test case based on [FullDeviceTest](https://github.com/greatscottgadgets/luna/blob/6c4c68d6649c10ee9e18047fc0cb8853e5eb5054/luna/gateware/usb/usb2/device.py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) that demonstrates the problem in simulation:

```python3
# Read our configuration descriptor (with subordinates).
try_config_length = 33
handshake, data = yield from self.get_descriptor(DescriptorTypes.CONFIGURATION, length=try_config_length)
self.assertEqual(handshake, USBPacketID.ACK)
self.assertEqual(bytes(data), self.descriptors.get_descriptor_bytes(DescriptorTypes.CONFIGURATION)[:try_config_length])
```

If I set `try_config_length` to 32 or less, the test case passes. If 33 or larger, it fails. Examining the simulation output in GTKWave, I tracked the apparent culprit to [this line in ConstantStreamGenerator](https://github.com/greatscottgadgets/luna/blob/6c4c68d6649c10ee9e18047fc0cb8853e5eb5054/luna/gateware/stream/generator.py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), which appears to be sized wrong (5 bits wide) for the intent of `max_length_width`, which I take to express the number of bits used to represent `max_length`. Indeed, if I change that line from:

```python3
bytes_sent     = Signal.like(self._max_length_width)
```

...to:

```python3
bytes_sent     = Signal(self._max_length_width)
```

...the test case passes. That is, until I reach `try_config_length` of 64, which fails for a different reason which I imagine is a separate issue.

```
...
  File "./enumerate_test.py", line 155, in test_enumeration
    handshake, data = yield from self.get_descriptor(DescriptorTypes.CONFIGURATION, length=try_config_length)
  File "/home/jboone/src/fpga/luna/luna/gateware/test/usb2.py", line 512, in get_descriptor
    descriptor = yield from self.control_request_in(0x80,
  File "/home/jboone/src/fpga/luna/luna/gateware/test/usb2.py", line 434, in control_request_in
    pid, packet = yield from self.in_transfer(data_pid=USBPacketID.DATA1)
  File "/home/jboone/src/fpga/luna/luna/gateware/test/usb2.py", line 350, in in_transfer
    pid, packet = yield from self.in_transaction(
  File "/home/jboone/src/fpga/luna/luna/gateware/test/usb2.py", line 323, in in_transaction
    self.assertEqual(pid, data_pid.byte())
AssertionError: 75 != <USBPacketID.128|64|DATA0|ACK|OUT: 195>
```

If I were to guess, this is a wMaxPacketSize0 issue, but that's just intuition speaking, not real data.

I'm holding off submitting a pull request, because I'm skeptical my ConstantStreamGenerator change is the extent of what's necessary. I just don't grasp the code well enough yet to know that the change I made was the appropriate one, as the meaning of `max_length` and `max_length_width` seem a bit muddled in my brain...

hansfbaier, 2021-03-03:
This is what the symptoms look in wireshark.
Request:
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
Response:
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

hansfbaier, 2021-03-03:
Here is my UAC2 example:
https://github.com/hansfbaier/luna/blob/uac2/examples/usb/usb2_audio.py

zyp, 2021-03-24:
Hi, has there been any progress on this so far? We're running into the same problem and I just want to make sure that I'm not duplicating any effort if I start digging into this.

hansfbaier, 2021-03-24:
@zyp Not from my side. I will steer clear. Thanks for looking into this!

hansfbaier, 2021-03-24:
@zyp Which problem are you referring to, the missing ISO Endpoint?

hansfbaier, 2021-03-24:
@zyp No I have not investigated this. I will steer clear. Thanks for looking into that!

zyp, 2021-03-25:
Per https://github.com/greatscottgadgets/luna/blob/main/luna/gateware/usb/usb2/control.py#L201, support for control responses larger than 64B is simply not implemented yet.

I hacked together a working solution, but I've got a meeting coming up in a few minutes, so I don't have time to clean it up into something PR-worthy right now, but here's the patch if anybody wants a go: https://paste.jvnv.net/view/D81fZ

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

twam, 2021-03-25:
Sorry for the late replay. We already now that this is missing.

@ktemkin even had some hints on IRC and Twitter (?) how this is supposed to be fixed.

hansfbaier, 2021-03-25:
@zyp Wow you're awesome, thanks!

hansfbaier, 2021-03-25:
@zyp What application is that screenshot from?

zyp, 2021-03-25:
@hansfbaier Total Phase Data Center.

@twam I'd appreciate an URL to those hints so I can adapt my solution accordingly.

twam, 2021-03-25:
I asked about the issue on 2021-02-08 in #luna-usb on FreeNode. The 1bitsquared discord (https://1bitsquared.com/pages/chat) has a history of that in the #luna channel. I can also provide you a log/screenshots if you reach out via @twamueller on Twitter or twam@twam.info on mail.

zyp, 2021-03-26:
Relevant line from the chat history:

> there's a `InTransferManager` meant to be used in the control EP that's currently not patched in properly

I've now made an attempt at doing that, but that's a more involved change than my workaround from yesterday and I have not managed to get everything to work correctly, so I think I'll pass on this for now and stick with the workaround until somebody have time to solve it properly.

hansfbaier, 2021-03-31:
@zyp I tried the fix, but got this:
```
[ 2988.184141] usb 5-4: new high-speed USB device number 16 using xhci_hcd
[ 2988.333853] usb 5-4: unable to read config index 0 descriptor/start: -71
[ 2988.333857] usb 5-4: can't read configurations, error -71
[ 2988.460145] usb 5-4: new high-speed USB device number 17 using xhci_hcd
[ 2988.609851] usb 5-4: unable to read config index 0 descriptor/start: -71
[ 2988.609854] usb 5-4: can't read configurations, error -71
```

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

ktemkin, 2021-04-13:
This should be fixed, as of https://github.com/greatscottgadgets/luna/commit/bf54d334eda178c7eacb3f5df6097876e130e11e.

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

I'm optimistically closing the issue, but I very much welcome all testing. :)

twam, 2021-04-13:
Thanks a lot! This is awesome news! I'll try to give it a test on the week-end!

hansfbaier, 2021-04-13:
Thank you so much, Kate! I am thrilled to give it a go!

hansfbaier, 2021-04-14:
I tried with the MIDI interface example (which I pushed to the pull request yesterday),
and the get configuration request gets NAK'ed as it seems:
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

twam, 2021-04-29:
Sorry for the late feedback, but also works for me like a charm.

Closed 2021-04-13.

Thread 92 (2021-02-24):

design r0.4

mossmann, 2021-02-24:
- [x] Fix Sideband and Host port CC pins so that they are reliably detected as a sink. Allow PD sniffing but no TX.
- [x] Fix Target port CC pins so that it is reliably detected as a sink when unpowered, can be configured as a source or sink when powered, and can operate as a PD transceiver.
- [x] Reduce LED brightness.
- [x] Change schematic symbol(s) to use COPI/CIPO. (I had previously omitted that change because I thought it made sense for the pin names within the symbol to match the manufacturer's documentation as closely as possible, but more recently I noticed that the OSHWA guidance specifically says to update symbols.)
- [x] Move via near U6 to avoid silkscreen line.
- [x] Add TC2030-CTX as alternative to TC2030-IDC.
- [x] Possibly allow 5 V input on Tag-Connect (J10) through a diode.
- [x] Move RST button trace away from board edge.

mossmann, 2021-03-11:
The only things that might need to change in gateware from r0.3 are CC and SBU pin assignments and handling, but those things don't yet exist for r0.3.

Closed 2021-03-16.

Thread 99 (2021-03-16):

Component substitution question

pk-r7, 2021-03-16:
Trying to build a development version of this board, I noticed some of the components have very long leadtimes across the entire US supply.
Specifically the FPGA and the oscillator.
The next step up in the ECP5 line is the LFE5U25. It is available and appears to be electrically compatible, I assume it would make a good replacement?
The entire line of SiTime oscillators is on a really long leadtime. I tried to compare footprints and specs and the closest I could find is a CMOS oscillator ASEM1-60.000MHZ-LC-T, however the ISA20-32AH-60.000MHZ is slightly larger and is an LVCMOS. Can anyone recommend a good replacement?

mossmann, 2021-03-16:
Yes, you can use LFE5U-25F, but I believe it will require one line to be changed in the gateware/platform file. Have you checked with Digi-Key? It appears that they have LFE5U-12F in stock, and they have SIT1602BC-23-33E-60.000000E as a "value added item" which I think always shows 0 stock even when they are able to fill orders.

I think the ASEM1-60.000MHZ-LC-T should work fine. However, we thought that the DSC60XX used prior to r0.3 would work, but it turned out to not be stable enough for reliable sustained USB transfers. The only oscillators we have thoroughly tested and approved are from the SiT1602B series.

If you haven't ordered PCBs yet, I suggest using the [r0.4 branch](https://github.com/mossmann/luna/tree/r0.4) (#97).

ktemkin, 2021-03-16:
> Yes, you can use LFE5U-25F, but I believe it will require one line to be changed in the gateware/platform file.

If you have the board plugged in before you run the relevant nMigen script (which builds the gateware), the library will automatically detect the FPGA size and everything should work transparently. IIRC, you'll only have to tweak the `device` constant if you don't have the board plugged in when you build the gateware. :)

>  SIT1602BC-23-33E-60.000000E as a "value added item" which I think always shows 0 stock even when they are able to fill orders

The SiTime oscillators are programmable, so usually most vendors display themselves as having only the unprogrammed ones in stock. Some vendors (like DigiKey) will program them for you, but always show them as out of stock, since they make them on demand. Another option is to buy the unprogrammed oscillators and the programmer for them, which IIRC isn't all _that_ expensive.

pk-r7, 2021-03-16:
Thanks for the explanation on the oscillators. I tried to order them as a value added item, Digikey quoted me a leadtime of 24 to 26 weeks on the value added oscillator. Digi has the programmer at ~240, a bit much for a one off build. I just asked again if they would reprogram some for me.

I did order off of the r0.4 branch from oshpark and oshstencils. Planned on sharing the project once I got them and confirmed the build.

mossmann, 2021-03-16:
Be aware that the OSH Park 4-layer stack-up differs from the stack-up specified for LUNA. I don't think it is likely to be an issue, but you _might_ see signal integrity problems using longer USB cables, for example.

pk-r7, 2021-03-16:
> Be aware that the OSH Park 4-layer stack-up differs from the stack-up specified for LUNA. I don't think it is likely to be an issue, but you _might_ see signal integrity problems using longer USB cables, for example.

More to learn, thanks for giving me a heads up on that.

pk-r7, 2021-04-09:
I discovered different issue during assembly. I can open a separate issue if you prefer.
U2 and U14 are listed as 74AUP2G126. I originally ordered X2SON units by using the 3dshape as a reference instead of what  I think is supposed to be a DFN1210-8 based off of the footprint.

Assuming I have the package correct, may I suggest you change the reference in the BOM to 74AUP2G126RA3-7?

I ended up getting a different package with a slightly longer overall length but same pinout to attach I may or may not replace with the correct components once I get them. (Those package sizes are a nightmare to solder by hand)
X2SON and XSON8 shown in the attached image (neither are the correct component).
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

mossmann, 2021-04-09:
> Assuming I have the package correct, may I suggest you change the reference in the BOM to 74AUP2G126RA3-7?

Oops! That is a bug. I intended to specify Diodes Inc. 74AUP2G126RA3-7.

gregdavill, 2021-04-23:
> I ended up getting a different package with a slightly longer overall length but same pinout to attach I may or may not replace with the correct components once I get them. (Those package sizes are a nightmare to solder by hand)

I also did the exact same thing, and ordered a part that's _slightly_ longer. I even checked and confirmed it wasn't the X2SON package, but didn't catch the slight pitch difference. :laughing:
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

mossmann, 2021-08-30:
I've fixed this bug in #130 and will close this issue after r0.5 is merged.

mossmann, 2023-07-15:
closing as this was merged in #190 and has now migrated to https://github.com/greatscottgadgets/cynthion-hardware

Closed 2023-07-15.

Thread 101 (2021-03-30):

debug_spi.py build broken

hstarmans, 2021-03-30:
Thanks for all the hard work on Luna.
I would like to inform you of an issue which was introduced in commit https://github.com/greatscottgadgets/luna/commit/db754379448e606c4e80bb499ef052abcaec4183
If I build debug_spi.py with code after this date it does not build correctly and the hierarchy is flattened.
```console
starmans@starmans-virtualbox:~/Downloads/luna/examples/hw_features$ python3 debug_spi.py --dry-run
WARNING | __init__    | Couldn't auto-detect connected platform. Assuming LUNA r0.2.
INFO    | __init__    | Building for LUNA r0.2...
/home/starmans/Downloads/luna/luna/gateware/utils/cdc.py:45: DriverConflict: Signal '(sig output__sdo__o)' is driven from multiple fragments: top, top.<unnamed #3>; hierarchy will be flattened
  output = Record.like(signal)
Warning: Wire top.$flatten\interface.$sample$s$serial_clock$sync$1 has an unprocessed 'init' attribute.
INFO    | __init__    | Build complete.
```
If I do a git checkout
```
git checkout f54de01c9dc13aeca5d20734a9c103227cb9603f
```
Subsequently a build
```console
starmans@starmans-virtualbox:~/Downloads/luna/examples/hw_features$ python3 debug_spi.py --dry-run
WARNING | __init__    | Couldn't auto-detect connected platform. Assuming LUNA r0.2.
INFO    | __init__    | Building for LUNA r0.2...
INFO    | __init__    | Build complete.
```
The flattening error disappears.
It should be relatively straightforward to test.

Regards,

Rik

hstarmans, 2022-05-05:
in cdc.py on line 64 (currently), I read
```python
if isinstance(signal[name], (Record, Pin)):
```
Before commit commit https://github.com/greatscottgadgets/luna/commit/db754379448e606c4e80bb499ef052abcaec4183 this was ,
```python
if isinstance(signal[name], Record) and (len(layout.fields) > 1):
```
If I go back to the old change. The code again works and I do not get complaints about missing clocks etc.

hstarmans, 2024-06-02:
Update 2-06-2024, bug is still there

hstarmans, 2024-06-07:
okay gonna close this if there is a pull request which is gonna fix this

Closed 2024-06-07.

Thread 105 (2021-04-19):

Stream endpoint locks up

zyp, 2021-04-19:
Hi, I've got a `USBMultibyteStreamInEndpoint` that's being fed by a 16-byte wide stream with the `first` and `last` flags set, i.e. always sending 16B packets. This appears to work fine at lower data rates, but when I reach roughly 12k packets per second, it locks up in less than a minute.

Once it is locked up, the `ready` signal on the stream is stuck low, while polls to the endpoint are NAKed. Other functions appears to be unaffected and the device will happily reenumerate if I unplug it and plug it back in, but the endpoint remains stuck until I reset the FPGA.

Here's an excerpt from a bus capture:
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

zyp, 2021-04-19:
FWIW it fails in the same manner when downconverting the stream and feeding it to a regular `USBStreamInEndpoint`, so the issue is not limited to the `USBMultibyteStreamInEndpoint`.

ktemkin, 2021-04-20:
Interesting -- from our Discord exchange:

> the fact that it's NAK'ing, though, makes me suspect that maybe there's a logic bug in the state tracking that's making it think it's empty when it's not

Is there any chance you could hook up one of the LUNA ILAs and try to grab a capture of the various buffer pointers? A VCD of that might help a bunch with diagnosing things. :)

zyp, 2021-04-20:
I don't have access to hardware to test on right now, but I just eyeballed the code and have a theory about what is going on. Excerpt from [transfer.py](https://github.com/greatscottgadgets/luna/blob/main/luna/gateware/usb/usb2/transfer.py#L314):

```python3
                    # Otherwise, there's a possibility we already have a packet-worth of data waiting
                    # for us in our "write buffer", which we've been filling in the background.
                    # If this is the case, we'll flip which buffer we're working with, toggle our data pid,
                    # and then ready ourselves for transmit.
                    packet_completing = in_stream.valid & (write_fill_count + 1 == self._max_packet_size)
                    with m.Elif(~in_stream.ready | packet_completing):
                        m.next = "WAIT_TO_SEND"
                        m.d.usb += [
                            self.data_pid[0]   .eq(~self.data_pid[0]),
                            read_stream_ended  .eq(0)
                        ]

                    # If neither of the above conditions are true; we now don't have enough data to send.
                    # We'll wait for enough data to transmit.
                    with m.Else():
                        m.next = "WAIT_FOR_DATA"
```

`packet_completing` doesn't account for the possibility of it being a short packet, which means that if we get the ACK in the same cycle as the last byte of the next packet, we'll move back to `WAIT_FOR_DATA` rather than `WAIT_TO_SEND`. Since the buffers are now full, `WAIT_FOR_DATA` is never getting `will_end_packet` and therefore remains stuck there.

I believe adding a check for `in_stream.last` to `packet_completing` will fix the problem and will test this later tonight.

zyp, 2021-04-20:
I just ran tests with and without the patch in #106.

Without the patch it locked up in 13 seconds. With the patch it ran for over ten minutes without any issues.

Closed 2021-04-26.

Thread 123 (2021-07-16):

Trying to run interactive-test.py on r0.2 luna board

tcal-x, 2021-07-16:
There's a non-zero chance of user error here.   This is what I attempted (from memory):

* I created and entered a virtual environment (python -m venv)
* In nmigen/nmigen/, I ran `python3 ./setup.py install`
* In greatscottgadgets/luna/, I ran `pip3 install poetry`, `poetry install`
* I connected a cable from my laptop's USB port to the Luna board's "Debug/Alt Port"
  * There was a slow-blinking green LED, and a row of dim red (w/ one green) LEDs
* I ran `poetry run applets/interactive-test.py`
  * The green LED(s) momentarily ran a bouncing back and forth pattern
  * The row of red LEDs got brighter
  * This output was returned on the terminal:
```
INFO    | __init__    | Building and uploading gateware to attached LUNA r0.2...
INFO    | __init__    | Upload complete.
INFO    | selftest    | Connected to onboard debugger; hardware revision r0.2 (s/n: eebbd5a905b435050213e29382f031ff).
INFO    | selftest    | Running tests...

Automated tests:
        Debug module:   ✗ FAILED        (register 1 was 63, not expected 1413829460)
        Host PHY:       ✗ FAILED        (PHY register 0 was 3182280431, not expected 36)
        HyperRAM:       ✗ FAILED        (RAM register 0 was 3182280431, not one of expected (3201, 3206))
        Sideband PHY:   ✗ FAILED        (PHY register 0 was 3182280431, not expected 36)
        Target PHY:     ✗ FAILED        (PHY register 0 was 3182280431, not expected 36)
```

FFY00, 2021-07-16:
FYI me and @perigoso were seeing similar, if not the same, failures due to the oscillator, which is quite finicky.

tcal-x, 2021-07-16:
> FYI me and @perigoso were seeing similar, if not the same, failures due to the oscillator, which is quite finicky.

Thanks, that's useful info!   Is there any known workaround?

FFY00, 2021-07-16:
See https://github.com/greatscottgadgets/luna/wiki/Hardware-Changes#revision-02-1. If you are not using the new oscillator, that'd be a starting point. We were not able to get the recommended oscillator where we live, so we had to order equivalents, the ones I ordered did not work, the ones @perigoso ordered did. If you need, we could dig up the part number for you.

tcal-x, 2021-07-16:
Thanks @FFY00 ; it's probably beyond my ability to replace a chip on the board.    I swear I saw some images calling out the parts on the Luna board (not sure if r0.2 or the new one or both), but now I can't find them.

Closed 2021-07-16.

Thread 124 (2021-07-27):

Future of LUNA?

nekrondev, 2021-07-27:
I'm not quite sure whatever reason has led for @ktemkin to retire from the LUNA project and to resign from GSG, but I'm wondering how the former head of software development and main contributor to LUNA project and it's USB tools will be substituted in the future?

I've backed LUNA H/W at Crowdsupply because I've got deep respect for the work of Kate regarding this project and her attitude in general so this was the main reason I voted to support GSG and her work.

Reading about the break up just 24h's after the campaign had started was a hit in the face for me and somehow found betrayed.
Even the best H/W that for sure GSG will deliver next year is worthless if the software development has stalled.

Please, a clear statement from @mossmann or whoever is responsible for this farce would be very appreciated.

mossmann, 2021-07-27:
While Kate was a very important part of the team and her contributions will be missed, LUNA is a team project. We are currently refocusing our remaining team members on LUNA to ensure the project gets proper support, and we will be hiring soon to keep the project on track for release. Already on our team is @miek who has developed hardware, gateware, and software for Amalthea, a project based on LUNA, and I took over LUNA hardware design work last year. Please be assured that software development efforts will resume and that LUNA will ship as planned with all capabilities listed on Crowd Supply.

ktemkin, 2021-07-27:
Personally, I have a lot of respect for @miek's abilities -- he's worked on LUNA-like projects in the past, and has been a contributor to a variety of nMigen-language projects. While I can't speak for GSG or their plans, I do have a lot of faith in @miek's ability to get the gateware/software side of things done.

nekrondev, 2021-07-28:
@mossmann: Thanks for clarification of the current situation and how it will evolve in the near future. I personally have high hopes getting a smashing brilliant USB tinkering device based on the fundamental work of Kate and Mike's further improvements.

@ktemkin  @miek: Good luck and all the best to current and former LUNA project members.

Closed 2021-07-28.

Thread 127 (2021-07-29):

USBInTransferManager does not toggle DATA when sending ZLP

ronyrus, 2021-07-29:
ZLP is sent with the DATAX PID, which is supposed to be toggled from the previous value.
It seems USBInTransferManager is not doing that.

When sending ZLP, we do need to toggle DATA, but we don't need to swap the buffers.
Right now, these two functions are done by the same signal.
Hence we need to split them.

miek, 2021-08-13:
Great find! I can confirm this in practice too.

I setup a test by patching the bulk_in_speed_test applet to limit the transfer size on the device side:

```patch
diff --git a/applets/bulk_in_speed_test.py b/applets/bulk_in_speed_test.py
index d332a62..a2b6c39 100755
--- a/applets/bulk_in_speed_test.py
+++ b/applets/bulk_in_speed_test.py
@@ -199,10 +199,16 @@ else:
             )
             usb.add_endpoint(stream_ep)

+            TRANSFER_SIZE = 8191
+            counter = Signal(range(TRANSFER_SIZE))
+            with m.If(stream_ep.stream.ready):
+                m.d.usb += counter.eq(Mux(stream_ep.stream.last, 0, counter + 1))
+
             # Send entirely zeroes, as fast as we can.
             m.d.comb += [
                 stream_ep.stream.valid    .eq(1),
-                stream_ep.stream.payload  .eq(0)
+                stream_ep.stream.payload  .eq(0),
+                stream_ep.stream.last     .eq(counter == TRANSFER_SIZE-1),
             ]

             # Connect our device as a high speed device by default.
@@ -245,6 +251,7 @@ def run_speed_test():

             # Count the data exchanged in this packet...
             total_data_exchanged += transfer.getActualLength()
+            print(transfer.getActualLength())

             # ... and if we should terminate, abort.
             if _should_terminate():
```

Which gives the following output as expected:

```
$ python3 bulk_in_speed_test.py
INFO    | __init__    | Building and uploading gateware to attached LUNA r0.4...
INFO    | __init__    | Upload complete.
INFO    | bulk_in_speed_test| Giving the device time to connect...
INFO    | bulk_in_speed_test| Starting bulk in speed test.
8191
8191
[...]
8191
8191
INFO    | bulk_in_speed_test| Exchanged 1.056639MB total at 44.90738769524466MB/s.

```

If I change the `TRANSFER_SIZE` to 8192 (a multiple of the packet size) to force ZLPs to be generated, the output is:

```
$ python3 bulk_in_speed_test.py
INFO    | __init__    | Building and uploading gateware to attached LUNA r0.4...
INFO    | __init__    | Upload complete.
INFO    | bulk_in_speed_test| Giving the device time to connect...
INFO    | bulk_in_speed_test| Starting bulk in speed test.
16384
16384
[...]
16384
16384
INFO    | bulk_in_speed_test| Exchanged 1.06496MB total at 44.79981934546913MB/s.
```
Suggesting that the ZLPs are being dropped by the host because the PID is incorrect, and the transfer size is limited to 16384 as defined by the host.

After applying your patch, the transfer size is correct for the second test.

miek, 2021-08-16:
I think there might be a similar bug in exiting the `WAIT_FOR_DATA` state. It does need to swap the buffers, but I'm not sure it should be toggling the data pid there?

miek, 2021-08-20:
> I think there might be a similar bug in exiting the `WAIT_FOR_DATA` state. It does need to swap the buffers, but I'm not sure it should be toggling the data pid there?

Nevermind, that is fine - it's just done there instead of right after the ACK because it couldn't swap the buffer yet. I may follow up with a commit to simplify things after merging the PR.

ronyrus, 2021-08-20:
I was AFK for some time, sorry for the lack of response.
Yeah, other cases seems to be OK and I agree, it would be great to simplify the code in this area.

Closed 2021-08-20.

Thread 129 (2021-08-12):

Case silkscreen feedback

cyrozap, 2021-08-12:
Yesterday, [a photo of the case](https://cdn.discordapp.com/attachments/816773068277809182/875107561060327525/image0.jpg) that was posted in the Discord channel. I was told to post my feedback regarding the silkscreen design here, so I'm doing that now.

I'll preface these statements by saying that I'm not a designer and don't have any experience in that area--these are just the issues that I, as a (future) user, had with the design. So, please don't grant these statements any undue authority. Also, these are just my opinions, so please feel free to ignore them if you think they're wrong.

# Issues

## Text orientation

My first issue is that the text is oriented in three directions, and somewhat inconsistently so. For instance, the "Host" and "Sideband" labels are rotated 90 degrees clockwise, and the "Target" label is rotated 90 degrees in the opposite direction. That all makes sense, since it means you can easily read the labels while looking at the ports you're plugging cables into. But then the labels for the "DFU" and "Reset" buttons have no rotation, despite the buttons being on the same sides of the case as those ports whose labels are rotated 90 degrees. I can understand the thought process behind that--the expectation is that the device would primarily be oriented with the ports on the left and right sides, and the user can easily read the "DFU" and "Reset" labels in that orientation and then just feel for the buttons. But to have text that's so close together oriented perpendicularly, as in the case of the "Sideband" and "DFU" labels, is somewhat confusing, and doesn't look very good. But then rotating "DFU" to be in line with "Host and "Sideband" would put it in conflict with the "Debug" LED labels, so something would need to be done about those, too.

## Indicators for each port's size

Without port width indicators like the "Target" label has (the lines the the left and right of the text), it's non-obvious where each port starts and ends. e.g., it'd be nice to see something like `┌──Host──┐┌Sideband┐` (or `┌──Host──┬Sideband┐` or whatever) to make that more clear.

## LED labeling

Similarly, the "Debug" and "FPGA" labels could use some separation from and better indication of what LEDs they cover. For instance, maybe the LED spots could have a line covering all them, and then put the "Debug"/"FPGA" labels above that line. Maybe something like this (but with the text actually underlined as well):

```
__Debug__   ___FPGA____
● ● ● ● ●   ● ● ● ● ● ●
A B C D E   5 4 3 2 1 0
```

Or, if labels start to get cluttered, the LED labels could be put in a "call out" (I don't know if that's the right term), where a line goes over the top of the LED spaces and links to a different area where the actual labels are. Kind of like what you might see on some PCBs with densely-packed clusters of components.

## Clutter

The design is simultaneously "too cluttered" and "has too much negative space". What I mean by that is, first, it seems the logos for the Luna itself and GSG were placed to fill as much of the space as they could, while leaving a large empty space in the middle. That's not to say I'd like to see that space filled--rather, I think it would be better to decrease the sizes of both logos, and also possibly even condense them into one (GSG logo plus "LUNA" text, and nothing else) or put them on the back of the case. Speaking of which...

The CE mark should not be on the front of the case. I realize that it was probably placed there since it may cost less to only mark the top side of the case, but whether or not something is CE-certified is generally not something I need to stare at every day. Instead, what I as a user find useful to see are the following (in no particular order):

- The port labels (so I know what to plug where, without having to consult the manual).
- The LED labels (again, so I don't have to consult the manual to know what they mean).

So if it's at all possible, I would suggest putting the full Luna logo and the CE mark on the back of the case, and then, since the GSG name is already a part of the Luna logo, skip the GSG gears entirely. Or, the GSG logo could be kept on the front side, but centered.

# Design mockup

A picture's worth a thousand words, so here's a sloppy mockup I did of a "fixed" design:

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

The two big circles are where the GSG logo would go. The design is not to scale (again, it's a sloppy mockup), and so maybe some of these design decisions might not work exactly, but I think this does a decent job illustrating my suggestions. I'm still not really happy with the labeling for the FPGA LEDs, since having all the digits in a horizontal line makes me want to read them like a single number, but I can't really think of a much better way to do that that wouldn't end up making some other aspect of the design worse.

Anyways, I'm eager to hear what people think about my comments/mockup.

perigoso, 2021-08-12:
I like these suggestions

A tiny detail I'd also change is the reset label, from "RESET" to just "RST", makes it more symetric with DFU and since the button itself occupies a small area it helps pinpoint it

straithe, 2021-08-13:
I really like your proposal for labelling the LEDs!

eduncan911, 2021-09-06:
I used the CrowdSupply contact page to ask them about my purchase and getting a blank case instead.  This was the reply:

> Thank you for your question and suggestion! We will not be doing a run of blank LUNA cases, but we will eventually be releasing design files so you can 3D print your own case, if you desire.
>
> BP

Closed 2021-10-15.

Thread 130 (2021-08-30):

design r0.5

mossmann, 2021-08-30:
- [x] populate FPGA self-programming passives
- [x] document U2, U14 part selection: Diodes Inc. 74AUP2G126RA3-7
- [x] do not populate SWD/JTAG connectors J5, J6
- [x] add ATSAMD11D14A-MNT as alt part for U6
- [x] populate Pmod connectors J7 and J11
- [x] improve D9 footprint
- [x] give D9 a 3d model
- [x] document D9 substitution(s)
- [x] make resistor precision notation (value field) consistent
- [x] add part selection for Pmod connectors J7 and J11
- [x] clarify USB3343-CP part number
- [x] update U1, U12, U13 part number (see #171)
- [x] update D1, D8 part number to reduce reverse leakage

mossmann, 2021-08-30:
Work in progress is here: https://github.com/mossmann/luna/tree/hw-r0.5

mossmann, 2023-01-11:
I decided against:
- maybe nudge J3 position
- maybe improve U2, U14 paste layer

Closed 2023-01-18.

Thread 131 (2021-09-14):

Logging change commit broke Python 3.7 compatibility

supersat, 2021-09-14:
After updating my repo, I began getting several strange errors:

```
supersat@Karls-iMac luna $ examples/blinky/blinky.py
Traceback (most recent call last):
  File "examples/blinky/blinky.py", line 41, in <module>
    top_level_cli(Blinky)
  File "/Users/supersat/Projects/luna/luna/__init__.py", line 83, in top_level_cli
    configure_default_logging()
  File "/Users/supersat/Projects/luna/luna/__init__.py", line 30, in configure_default_logging
    logger.basicConfig(level=logging.INFO, format=log_format, force=True)
  File "/Library/Frameworks/Python.framework/Versions/3.7/lib/python3.7/logging/__init__.py", line 1921, in basicConfig
    raise ValueError('Unrecognised argument(s): %s' % keys)
ValueError: Unrecognised argument(s): force
```

It turns out the force keyword was added recently in commit 488d9954186f2d89e023cbfdafee5d22b29e7f53, but is only supported in Python 3.8 or above (see https://docs.python.org/3.8/library/logging.html#logging.basicConfig vs https://docs.python.org/3.7/library/logging.html#logging.basicConfig), while pyproject.toml and the documentation both say Python 3.7 is the minimum supported.

Not sure what the solution is here: bump the Python requirement to 3.8, or use force=True only if Python >= 3.8?

miek, 2021-09-14:
doh, good catch - thanks! I've reverted that and pushed a better fix for the original problem.

Closed 2021-09-14.

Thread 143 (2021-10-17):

SoC: usb_device_connect=0 does not disconnect device

gregdavill, 2021-10-17:
I'm using Luna as a HS USB wishbone peripheral in a SoC bootloader design for the ButterStick. I'd like to be able to disconnect the USB interface from firmware to support re-enumeration.

`USBDevice.connect` is a signal that is connected via the standard SoC interface, Which has the following description:
```
class USBDevice(Elaboratable):

    Attributes
    ----------

    connect: Signal(), input
        Held high to keep the current USB device connected; or held low to disconnect.
```

If I hold connect low on power-up the device never appears, as expected. When I pull this signal high the device appears, as expected. However If the device is attached then pulling this signal low I'd expect the host to detect we've disconnected. But that is not the case.

The gateware seems to remove the termination if connect drops low.
```python
self.utmi.term_select.eq(reset_sequencer.termination_select & self.connect),
```

But this results in termination being set to 0. Which is defined as `HS_NORMAL`
```python
class UTMITerminationSelect:
    """ Enumeration that specifies meanings of the UTMI TermSelect bit. """

    HS_NORMAL    = 0
    HS_CHIRP     = 1
    LS_FS_NORMAL = 1
```

A quick fix I've found is to mask `vbus_connected` with `self.connect`. So that when we bring 'self.connect' `LOW` it's equivalent in logic to a vbus removal. With this in place the device correctly disconnects.

This works, but I'm not sure if this is the correct place to perform this mask.
```diff
diff --git a/luna/gateware/usb/usb2/device.py b/luna/gateware/usb/usb2/device.py
index 67e4c6b..4956cd3 100644
--- a/luna/gateware/usb/usb2/device.py
+++ b/luna/gateware/usb/usb2/device.py
@@ -232,7 +232,7 @@ class USBDevice(Elaboratable):
         m.d.comb += [
             reset_sequencer.bus_busy        .eq(self.bus_busy),

-            reset_sequencer.vbus_connected  .eq(~self.utmi.session_end),
+            reset_sequencer.vbus_connected  .eq(~self.utmi.session_end & self.connect),
             reset_sequencer.line_state      .eq(self.utmi.line_state),
         ]

```

straithe, 2021-11-15:
Thank you for this information! I've upgraded this issue to bug status. I will leave this issue open until it is addressed.

martinling, 2024-06-21:
Fixed in #212.

Closed 2024-06-21.

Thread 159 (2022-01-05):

spike on ULPI D4, D7 data bus when asserting STP

ronyrus, 2022-01-05:
This happens from time to time.
When asserting STP in the end of TX, all the data lines are supposed to be 0x00 (or 0xFF in some cases), but in steady state.
Instead, from time to time a short spike can be observed on D4 and/or D7.
The pulse is 0.8v-1.9v with the duration of ~2.5 ns

Spike on D7: (red - STP, blue - D7)
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

Spike on D4
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

Seems to be not PHY specific. I was able to reproduce it on "host" and "target" PHYs.

To reproduce I've used the 'simple_device' design from the examples.
I'm able to trigger it on D7 with a single 'get_descriptor' control transfer.
It gets the STALL response, hence the try-except in the code.

```
#!/usr/bin/env python3

import time
import usb1

print("sending packets ... Ctrl-C to stop")
while True:
    try:
        with usb1.USBContext() as context:
            device = context.openByVendorIDAndProductID(0x16d0, 0x0f3b)
            device.claimInterface(0)
            device.controlRead(0x80, 6, 0x0600, 0x0000, 0x000A)
    except usb1.USBErrorPipe:
        print('.', end="", flush=True)
        time.sleep(0.5)
```

Later on was reproduced by @zyp
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

zyp, 2022-01-05:
IIRC when we discussed this on Discord, we came to the conclusion that it's caused by the ULPI IO not being registered but driven combinatorially.

The LUT input signals doesn't necessarily all have the same propagation delay, so when two or more inputs toggle in the same cycle, the LUT may briefly see a half-old half-new input state causing it to output the wrong value, causing glitches like this. (Picture an XOR gate with the inputs switching from 00 to 11; in either case the output should be 0, but if it briefly sees 01 or 10 in between you'll get a brief 1 on the output.)

This is not really indicative of a problem; as long as the PHY chip's setup and hold times are not violated, the glitch should be harmless.

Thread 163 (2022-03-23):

ECP5 protocol error for descriptors longer than 128 bytes

BrettRD, 2022-03-23:
I'm porting a bit of gateware from a Deca to a Colorlight, and I've run into a bug when using `GetDescriptorHandlerBlock` which is not encountered with `GetDescriptorHandlerDistributed`
Exploration here: https://github.com/amaranth-community-unofficial/deca-usb2-audio-interface/issues/5

If the descriptor grows to form a URB greater than 128 Bytes using `GetDescriptorHandlerBlock` it wraps and truncates the descriptor.

If I set `LUNA_AVOID_BLOCKRAM`, it uses a `GetDescriptorHandlerDistributed` instead and happily enumerates with a descriptor URB of 218 Bytes (packet size of 282 bytes)

This flag affects exactly one condition in Luna here: https://github.com/greatscottgadgets/luna/blob/08b035c9c2b053d7edffb0d220d948b5c2ca927e/luna/gateware/usb/request/standard.py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

These two descriptor handlers ought to have identical behaviour aside from timing constraints and resource usage

This bug seems to affect the ECP5 platform and not the DECA platform, so I suspect it's an issue related to platform-specific block-ram features and allocation

jboone, 2022-05-02:
I don't know how useful this data point is, but I've had LUNA USB enumeration problems, seemingly at random, which were magnified by adding a bunch of USB UAC descriptors from a [DECA-based audio project](https://github.com/amaranth-community-unofficial/deca-usb2-audio-interface/blob/main/gateware/deca_usb2_audio_interface.py). If I remove only those descriptors (but leave the ones for the non-audio portion of my project), the generated bitstreams are reliable. If I add back the audio project's descriptors (which are many!), the problem returns. If I use `LUNA_AVOID_BLOCKRAM` as suggested, the project with the audio descriptors seems so far to be entirely reliable. So I'm guessing there's some sort of block RAM timing closure or mischaracterization issue in prjtrellis? My USB clock timing winds up clearing the 60MHz requirement by more than 10MHz, so nextpnr *thinks* everything's cool. But maybe not...

BrettRD, 2024-11-21:
My apologies for the noise, this was a hardware bug with my ULPI device.

I'm using the Waveshare USB3300 which generates its own clock, and has a connector that makes it hard to have short trace lengths.  The FPGA is clocked from the ULPI so propagation delay counts double.
By *extending* the ULPI cable to about 200mm of total trace length and *inverting* the fpga clock input pin, I have made a cursed contraption that enumerates with long descriptors.

There is a timing (or perhaps glitch) difference between Block and Distributed handlers, but it's practically cosmetic.

Closed 2024-11-21.

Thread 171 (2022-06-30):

Find Substitution for AP22811, as it is FAULTY

Seas0, 2022-06-30:
The AP22811 have been marked as NOT RECOMMENDED FOR NEW DESIGN by Diodes lately, shall we consider use its successor, AP22818, as USB power switch at U1, U12, U13?
_Edit: both of them are ***NOT*** suitable for luna's design, see my latter comment._

mossmann, 2022-06-30:
Yes, AP22818AKEWT-7 looks like the drop-in replacement for AP22811AW5-7 which we have specified.  AP22811AW5-7 is still expected to ship, so I don't think we need to make a change urgently. We already have AP22804AW5-7 and AP22814AW5-7 designated as acceptable substitutes.

I think we should update the part number in the schematic to AP22818AKEWT-7 and add AP22811AW5-7 to the list of substitutes.

Seas0, 2022-07-04:
Well, after some careful examination, it seems the originally used DC switch, AP22811, and the candidate one, AP22818, is ***FAULTY*** in current [[design](https://github.com/greatscottgadgets/luna/blob/main/hardware/rev0/power_supplies.sch)](https://github.com/greatscottgadgets/luna/blob/main/hardware/rev0/power_supplies.sch).
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

Currently Luna's design assumed these DC switches should maintain the OUT port at High-Z when not enabled, either disable by the pull-down resistor or by FPGA.

But my self-built Luna's DC switches, U1 and U13, were getting ~100 Celsius after plugging in power supply to the target USB type-C port with about 2 watts drew from the power supply, indicating a huge current go through them, so I looked through the [[datasheet](https://www.diodes.com/assets/Datasheets/products_inactive_data/AP22811.pdf)](https://www.diodes.com/assets/Datasheets/products_inactive_data/AP22811.pdf) of AP22811 and found this:

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

The [[datasheet](https://www.diodes.com/assets/Datasheets/AP22816_17_18.pdf)](https://www.diodes.com/assets/Datasheets/AP22816_17_18.pdf) of AP22818 describe almost the same thing so I'd only provide a link to it for reference.

As cited in their datasheet, they both have the "Fast Discharge" functionality activated in the absence of EN signal, which is actually shorting OUT and GND with a MOSFET and/or a resistor, explained the weird overheating problem as current could flow back to the OUT port of a disabled DC switch and directly drive to ground, easily heating up the DC switch and wasting power of the USB Bus.

mossmann, 2022-07-04:
Nice find! I think you are right that the output discharge function is not ideal for our application, although I don't know that I would say that it is faulty or that it explains the U1/U13 failure you observed.

I measure discharge current at 35 to 40 mA which agrees pretty closely with the discharge resistance of 90 to 130 ohms specified in the data sheet. This is wasteful, but I don't know that it is a big problem.

If you find a more ideal part, I'd love to see it. Otherwise we could decide to accept the discharge current or we could place diodes on the outputs (which would reduce the voltage by the diode drop).

mossmann, 2022-07-04:
AP22818 has a discharge resistance of 140 to 200 ohms which is slightly less wasteful.

martinling, 2022-07-06:
Torex [XC8107](https://www.torexsemi.com/file/xc8107/XC8107.pdf) and [XC8108](https://www.torexsemi.com/file/xc8108/XC8108.pdf) are amongst the few alternatives without load discharge that currently have some stock availability. The XC8108 has the added feature that the current limit is configurable with a resistor.

mossmann, 2022-07-18:
My best guess is that the failure you observed was caused by VOUT overvoltage when VIN was at 0 V. Because of this as well as limitations of reverse current protection, we've been looking into various options and are likely to go with a FET-based solution rather than using integrated load switches.

straithe, 2022-12-08:
I'm closing this issue as there hasn't been any additional conversation in quite a while. Thanks all!

mossmann, 2022-12-08:
I'm reopening this because I'm still working on it.

mossmann, 2023-01-11:
I went with AP2171 on r0.5 to address the initial component lifecycle concern and self-discharge. The overvoltage issue I later identified will be addressed in r0.6.

Closed 2023-01-11.

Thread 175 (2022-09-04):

Question: alternate protocol support

symdeb, 2022-09-04:
Could LUNA be extended with other protocol analysis (SPI, I2C,MIPI etc..) using the 16 user defined I/O ports as generic I/O ports and bring those pins to the outside of the enclusure on a header ? This would make LUNA a very lucrative alternative to other $1000+ USB2.0 and multiprotocol analyzers. Not being familair with LUNA yet, suppose this would be grabbing a bunch of samples into the buffer and send them to the host software that for example Sigrok/PulseView or other open source software could analyze ?

martinling, 2022-09-04:
We've actually already made the change to bring those I/Os to the outside of the enclosure in the form of two PMOD ports. See [this update](https://www.crowdsupply.com/great-scott-gadgets/luna/updates/pmod-host-ports-added-to-encased-lunas) on CrowdSupply for more info.

It would certainly be possible to enable using those I/Os as a simple logic analyzer in exactly the way you describe. Writing the software and gateware to do that isn't on our priority list at the moment, as we need to focus on the USB features we've committed to, but it would be a fairly straightforward project.

symdeb, 2022-09-05:
Thank you. That tis really great. A few others question while having difficulties get through the Discord phone verification process (it seems to be locked up somehow) so post them here

1. Could not find "technial specifications" for LUNA: Curious for what is the internal sample rate ?  Other prduct use 1 to 2GHz (DSLogic/Zeroplus). What would the rate be for the user GPIO and what speed  in/out clockd could be created?

2. Read that memory is 8MB . Other products support 64~128MB  For USB HS, how many seconds of data could be stored in the buffer or is for HS ? Could memory be expanded  and would streamed transfer an viable option through the USB 3.0 host ?

martinling, 2022-09-05:
> Curious for what is the internal sample rate ? Other prduct use 1 to 2GHz (DSLogic/Zeroplus). What would the rate be for the user GPIO and what speed in/out clockd could be created?

LUNA doesn't work by sampling the USB data lines directly at high speed, there are USB 2.0 PHYs for each port which are used as the high speed interface.

The FPGA is connected to the ULPI interface of each PHY, which includes an 8-bit parallel data bus. Because of that 8-bit wide bus, the logic for capturing USB packets, buffering them and delivering them to the host only needs to run at 60MHz (8 x 60 = 480Mbit/s).

The simplest way to integrate GPIO capture would be to sample the PMOD I/Os at the 60MHz clock, and add the resulting data to the capture buffer. With a bit more work, they could potentially also be sampled/driven from another clock domain at a higher rate. The ECP5 I/O buffers are limited to 200MHz in / 150MHz out for LVCMOS, but can go up to 400MHz for LVDS. Buffer space and USB throughput for the logic data will be the main limiting factors though, especially if trying to capture USB at the same time.

> Read that memory is 8MB . Other products support 64~128MB For USB HS, how many seconds of data could be stored in the buffer or is for HS ? Could memory be expanded and would streamed transfer an viable option through the USB 3.0 host ?

Since we identify and capture USB packets on the FPGA, rather than just raw samples of the data lines, the duration we can store in memory depends on the USB traffic involved. In the most demanding scenario where the bus is fully utilized at HS, an 8MB buffer provides something like ~150ms of capture.

We can stream buffered packets to the host at around 40MB/s, so if the target bus utilization is moderate, or limited to short bursts of high traffic, it is possible to capture indefinitely. Due the overhead involved in streaming a HS capture over HS however, it's not possible to maintain continuous capture if the target bus is more heavily utilized.

It may be possible to achieve unlimited HS capture by a channel bonding approach using both the 'host' and 'sideband' ports for streaming, but this would require two cables to the host which would have to be attached to independent buses. Implementing this is not currently on our roadmap.

The current hardware does not have any support for USB 3.0. There is partial support for USB 3.0 in the LUNA gateware library, but utilising it will require a future product with different hardware.

symdeb, 2022-09-05:
Thank you much for the explanation.
Ideally that user IO could be used to test MII/RMII/GMII for ethernet, but those are  25, 50 and 150MHz respecitively.

For the USB use case faced is as follows:
1, Using libusb sending a control request frm a host PC to retrieve a interface descriptor from a device does not show anything
    going out in wireshark
2. Adding breakpoint in the USB device does not trigger a receipt for such packet
3. The USB device firmware  library creator would like to see "proof" that the request did go over USB before
     putting  the library into question.

This the idea was to use an analyzer to captrure if there was a really a transfer on bus:

1. At Full speed, the buffer might be large enough for several seconds of USB data
2. For High speed, the only way for longer capture is streaming over USB 3.0 to the host to gather sufficnet data

Approach 1:
A. Put the device in full speed and use a low cost USB analzyer. the reuslt would probably be the same at high speed
B. At high speed use a high cost capture device and a USB 3.0 PC host with sufficient speed to catch up the USB 3,0 data
So here is why LUNA came in as a low cost option for HS. The only question now is if the USB PC host is fast enough.
Please corretct me if this way of thought is incorrect or if there is better approach

martinling, 2022-09-05:
The other way around the USB 2.0 bottleneck is to do some packet filtering on the FPGA, to exclude things that aren't of interest. E.g. you could discard all traffic that's not on endpoint 0, which would keep the data rate down whilst still ensuring that you see the transfer you're looking for if it's there.

At the moment we don't have frontend features for doing that, but with our Amaranth workflow, an ad-hoc hack to add a filter on the FPGA side can be as simple as editing `luna/gateware/usb/analyzer.py` and re-running things.

symdeb, 2022-09-09:
That is a great feature for custom code for data manipulation and triggering. Looking at the schematic, the upstream USB is high speed. Even the ULPI runs at 60MHz,  all the data has to be moved upstream again to the host (PC).  if that is uncompressed the data amount would be about 1:1 (if not more if there is some overhead such as meta data), correct ?
Since the FPA need to cope with the "slow" upstream USB 2.0 ULPI interface, Would that not cause  congestion in the FPGA ?
In other words, were there any considerationto us an USB3.0 tranceiver instead that could reduce risk for such bottlenecks for streaming data to the host (PC) ? The FPGA would need to add functionality to interfae to such an USB 3.0 device controller.
Key question: Have any experiments been done if the USB HS streaming to the PC host can sustained over longer periods, say 5 to 10 seconds ?

zyp, 2022-09-09:
We're using the LUNA stack in [Orbtrace](https://github.com/orbcode/orbtrace), and I can share some performance numbers from our testing.

First of all, the theoretical max HS USB bulk capacity is 13 packets per microframe, and at 512B per packet and 8000 microframes per second, that comes out to 425.984 Mb/s (53.248 MB/s). We have however not been able to reach this in our testing, probably due to practical limitations with the host side scheduling and reserved capacity for other devices on the bus.

We've however been able to reach 12 packets per microframe which comes out to around 393 Mb/s (49 MB/s), and can sustain this as long as there's not a lot of other traffic on the bus fighting for capacity. We're doing this with only 8kB+1kB of buffering on the device side.

I figure more buffering is mainly useful if you've got bursty traffic with a reasonably large difference between peak and average data rates.

martinling, 2022-09-09:
Overhead depends somewhat on the nature of the traffic but let's work through a simple high-throughput case - capturing a single target device making one continuous flat-out bulk IN transfer with full 512 byte packets. Assume for the sake of simplicity that we're filtering out SOF packets and other traffic, and that nothing gets NAKed.

In that scenario, for each 512 bytes of payload data sent by the target device, LUNA will currently put 525 bytes into the capture buffer for the IN transaction:

- 2 bytes length header + 3 bytes IN packet
- 2 bytes length header + 3 bytes DATA0/1 packet fields + 512 bytes payload
- 2 bytes length header + 1 byte ACK packet

As @zyp notes, the realistic limit for one device is 12 of those transactions per microframe and there are 8000 microframes per second, so LUNA has to buffer 12 * 8000 * 525 B/s for a total of 50.4MB/s, and could stream that buffer to the host at 12 * 8000 * 512 B/s or 49.152MB/s. So the buffer would fill up at (50.4 - 49.152) = 1.248MB/s. With an 8MiB buffer that would correspond to 6.72s of capture time. But if we can compress the buffered data on the FPGA side by even just 3%, then it becomes possible to capture indefinitely.

In most practical scenarios, HS throughput to the host should be sufficient to get things done, especially when combined with all the filtering and triggering logic that's possible through customising the analyzer gateware. Adding a USB 3.0 transceiver would have significantly increased the cost of the device. For scenarios where you really want to capture every detail of a completely saturated bus, there's always the possibility of using the second USB 2.0 port to increase throughput.

symdeb, 2022-09-20:
6 seconds would be more than enough to gather data. Looking at the schematic, the USB3343 is used.  Does LUNA support USB Low/full speed as well  . It would require to get the USB data, but not via ULPI,correct ?

martinling, 2022-09-20:
Yes, low and full speed capture are supported. At the moment you have to select which speed you want to capture, but on-the-fly speed detection is on the todo list.

Closed 2022-10-02.

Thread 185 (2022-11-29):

design r0.6

mossmann, 2022-11-29:
- [x] increase PCB size to accommodate future switch from 256 caBGA to 381 caBGA package
- [x] increase clearance around U8, U9, U11 (USB PHYs) to accommodate future switch from USB3343 to USB3320
- [x] rename Sideband port to "Control" and use as primary port for control of both FPGA and Apollo)
- [x] rename Host port to "Aux" for auxiliary functions including MitM
- [x] enhance Target-C PD/CC I/O with FUSB302B or similar Type-C controller
- [x] enhance Aux PD/CC I/O with FUSB302B or similar Type-C controller
- [x] connect shields of all USB connectors together
- [x] disconnect USB shields from GND except through ferrites or 0 ohm resistors (populated by default)
- [x] replace U1, U12, U13 (Target VBUS switches) with FET solution
- [x] add VBUS voltage and current monitoring for all USB ports
- [x] replace D1, D8 (5V diode OR) with FET solution
- [x] move HyperRAM to FPGA pins in a DQS group if possible for both 381 caBGA and 256 caBGA variants
- [x] increase clearance around U6 (microcontroller) to allow future replacement if necessary
- [x] restore 1.8 V supply as an assembly option, supporting either 1.8 V or 3.3 V HyperRAM
- [x] add pin straps for hardware version detection
- [x] increase LED spacing
- [x] add USB switch to Control port
- [x] improve microcontroller D+/D- routing/reference plane
- [x] remove Debug SPI test points
- [x] bigger and better mounting holes
- [x] add third button for SoC reset or general FPGA use
- [x] remove J5 (FPGA JTAG) if it is in the way
- [x] move Pmod connectors to the same side to support 24-pin Pmods
- [x] remove unpopulated SMA connectors
- [x] add FPGA->microcontroller interrupt signal
- [x] add mezzanine connector
- [x] add test points for DFU button
- [x] update layout with all of the above

Close this issue after validating the design and merging to main.

mossmann, 2023-02-07:
Work in progress is here: https://github.com/mossmann/luna/tree/hw-r0.6

yyrfejx884, 2023-03-24:
Can you add pin headers to target d- and d+ lines?

yyrfejx884, 2023-03-24:
There are some cases when you need to put some extra circuit on these lines temporarily for example: https://www.huaweinewos.com/huawei-harmonyos-support-harmony-tp-cable.html
In this case you need to put two pull-ups on the data lines till the fastboot loads then you can remove them and use the usb as normal.

mossmann, 2023-03-27:
> There are some cases when you need to put some extra circuit on these lines temporarily for example: https://www.huaweinewos.com/huawei-harmonyos-support-harmony-tp-cable.html In this case you need to put two pull-ups on the data lines till the fastboot loads then you can remove them and use the usb as normal.

We won't be adding a D+/D- pin header in r0.6 for the signal integrity reason @martinling mentioned and also due to lack of board area and time (we have already had r0.6 prototype PCBs made). Harmony TP interfacing will have to be done with an external cable or by soldering resistors to the through-hole TARGET A pins.

If you implement the USB communication with Cynthion (not a passthrough host), you could use the additional TARGET port as a place to plug in a small resistor circuit instead of using a special cable.

mossmann, 2023-07-15:
closing as this (and more) has been merged to: https://github.com/greatscottgadgets/cynthion-hardware

Closed 2023-07-15.

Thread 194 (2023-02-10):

Cannot install from git

jeremyherbert, 2023-02-10:
Hi,

When trying to install from git as per the documentation, I received the following error:

```
Creating virtualenv luna-MtvwdPsJ-py3.10 in /home/jeremy/.cache/pypoetry/virtualenvs
Installing dependencies from lock file

Because lambdasoc (0.1.dev27+gefd5442) @ git+https://github.com/ktemkin/lambdasoc.git@HEAD depends on nmigen (*) which doesn't match any versions, lambdasoc is forbidden.
So, because luna depends on lambdasoc (0.1.dev27+gefd5442) @ git+https://github.com/ktemkin/lambdasoc.git, version solving failed.
```

I saw in another issue I could instead try `pip install .`, but this also gives an error:

```
Defaulting to user installation because normal site-packages is not writeable
Processing /home/jeremy/Downloads/luna
  Installing build dependencies ... done
  Getting requirements to build wheel ... done
  Preparing metadata (pyproject.toml) ... done
Collecting amaranth-boards@ git+https://github.com/amaranth-lang/amaranth-boards.git@main
  Cloning https://github.com/amaranth-lang/amaranth-boards.git (to revision main) to /tmp/pip-install-r5euf53l/amaranth-boards_5e1919b96376435392db67a27f19d5e4
  Running command git clone --filter=blob:none --quiet https://github.com/amaranth-lang/amaranth-boards.git /tmp/pip-install-r5euf53l/amaranth-boards_5e1919b96376435392db67a27f19d5e4
  Resolved https://github.com/amaranth-lang/amaranth-boards.git to commit 609a65c163c1374fb5f9c528253c36caa8edd56f
  Installing build dependencies ... done
  Getting requirements to build wheel ... done
  Preparing metadata (pyproject.toml) ... done
  WARNING: Generating metadata for package amaranth-boards produced metadata for project name unknown. Fix your #egg=amaranth-boards fragments.
Discarding git+https://github.com/amaranth-lang/amaranth-boards.git@main: Requested unknown from git+https://github.com/amaranth-lang/amaranth-boards.git@main (from luna==0.1.0.dev0) has inconsistent name: filename has 'amaranth-boards', but metadata has 'unknown'
Collecting usb-protocol@ git+https://github.com/usb-tools/python-usb-protocol
  Cloning https://github.com/usb-tools/python-usb-protocol to /tmp/pip-install-r5euf53l/usb-protocol_867f717767d54f2c9f5da760f02d3564
  Running command git clone --filter=blob:none --quiet https://github.com/usb-tools/python-usb-protocol /tmp/pip-install-r5euf53l/usb-protocol_867f717767d54f2c9f5da760f02d3564
  Resolved https://github.com/usb-tools/python-usb-protocol to commit a9830731a8de6946bfee014e6b0188ee83a716f2
  Preparing metadata (setup.py) ... done
Collecting amaranth@ git+https://github.com/amaranth-lang/amaranth.git@main
  Cloning https://github.com/amaranth-lang/amaranth.git (to revision main) to /tmp/pip-install-r5euf53l/amaranth_f62391ffd97b4bc685174083be7a2465
  Running command git clone --filter=blob:none --quiet https://github.com/amaranth-lang/amaranth.git /tmp/pip-install-r5euf53l/amaranth_f62391ffd97b4bc685174083be7a2465
  Resolved https://github.com/amaranth-lang/amaranth.git to commit 666ee27fd0fa9fb90109e0e201f878f9ab034c85
  Installing build dependencies ... done
  Getting requirements to build wheel ... done
  Preparing metadata (pyproject.toml) ... done
  WARNING: Generating metadata for package amaranth produced metadata for project name unknown. Fix your #egg=amaranth fragments.
Discarding git+https://github.com/amaranth-lang/amaranth.git@main: Requested unknown from git+https://github.com/amaranth-lang/amaranth.git@main (from luna==0.1.0.dev0) has inconsistent name: filename has 'amaranth', but metadata has 'unknown'
Collecting amaranth-soc@ git+https://github.com/amaranth-lang/amaranth-soc.git@main
  Cloning https://github.com/amaranth-lang/amaranth-soc.git (to revision main) to /tmp/pip-install-r5euf53l/amaranth-soc_a01fc66bb4ce41f1a7613f4e087ec057
  Running command git clone --filter=blob:none --quiet https://github.com/amaranth-lang/amaranth-soc.git /tmp/pip-install-r5euf53l/amaranth-soc_a01fc66bb4ce41f1a7613f4e087ec057
  Resolved https://github.com/amaranth-lang/amaranth-soc.git to commit bddf5a82ff63ad55c13138a654da511317f6861c
  Installing build dependencies ... done
  Getting requirements to build wheel ... done
  Preparing metadata (pyproject.toml) ... done
  WARNING: Generating metadata for package amaranth-soc produced metadata for project name unknown. Fix your #egg=amaranth-soc fragments.
Discarding git+https://github.com/amaranth-lang/amaranth-soc.git@main: Requested unknown from git+https://github.com/amaranth-lang/amaranth-soc.git@main (from luna==0.1.0.dev0) has inconsistent name: filename has 'amaranth-soc', but metadata has 'unknown'
Requirement already satisfied: pyvcd<0.3.0,>=0.2.4 in /home/jeremy/.local/lib/python3.10/site-packages (from luna==0.1.0.dev0) (0.2.4)
Collecting ziglang<0.9.0,>=0.8.0
  Downloading ziglang-0.8.1-py3-none-manylinux_2_12_x86_64.manylinux2010_x86_64.whl (68.1 MB)
     ━━━━━━━━━━━━━━━━━━━━━━━━━━━━━━━━━━━━━━━━ 68.1/68.1 MB 1.9 MB/s eta 0:00:00
Collecting pyusb<2.0.0,>=1.1.1
  Downloading pyusb-1.2.1-py3-none-any.whl (58 kB)
     ━━━━━━━━━━━━━━━━━━━━━━━━━━━━━━━━━━━━━━━━ 58.4/58.4 KB 23.5 MB/s eta 0:00:00
Collecting libusb1<2.0.0,>=1.9.2
  Downloading libusb1-1.9.3-py3-none-any.whl (60 kB)
     ━━━━━━━━━━━━━━━━━━━━━━━━━━━━━━━━━━━━━━━━ 60.5/60.5 KB 28.7 MB/s eta 0:00:00
ERROR: Could not find a version that satisfies the requirement amaranth-boards (unavailable) (from luna) (from versions: 0)
ERROR: No matching distribution found for amaranth-boards (unavailable)
```

Could you please help me understand what the correct way to install this package is?

antoinevg, 2023-02-10:
The plan moving forward is to stop using poetry entirely in favour of pip.

`pip install .` _should_ be working at the moment against HEAD but it's good to know when it isn't!

Can you please provide a bit more info about your environment:

* OS & version
* Python version
* Are you using a virtual environment tool such as `virtualenv` or `pyenv` ?

Environments I've tested and can confirm work from a fresh environment:

* macOS 12 & 13, Ubuntu 22.04, Arch latest
* Python 3.10 and 3.11, PyPy 3.9

jeremyherbert, 2023-02-10:
Hi,

Sorry, I should have provided that info earlier. I’m using Ubuntu 22.04 with python from the apt repo, 3.10. The only other things installed via pip are litex and amaranth (and their dependencies). No virtual environment, I’m running a separate VM with the fresh Ubuntu install so there isn’t really a need for one.

antoinevg, 2023-02-10:
Ah okay, this could indeed be related to the recent shift amaranth made to `pyproject.toml`.

There's an open PR which is related:

https://github.com/greatscottgadgets/luna/pull/192/files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

In the meantime you could try this change on your local `requirements.txt`:

```diff
- -e git+https://github.com/amaranth-lang/amaranth.git#egg=amaranth
+ amaranth -e git+https://github.com/amaranth-lang/amaranth.git#egg=amaranth
```

jeremyherbert, 2023-02-11:
Seems that this problem is related to pip 22 which ships with ubuntu by default. Upgrading to pip 23 and using the PR you mentioned works fine.

Closed 2023-02-11.

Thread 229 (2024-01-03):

can't install luna in ubuntu 22.04

matisTopPath, 2024-01-03:
Hi, I try to install luna to Ubuntu 22.04 and run applets/interactive-test.py
But always show errors.

Would someone be able to give the environment lib list?
I have read the install documents, but I am not sure what's missing.

thanks alot.

miek, 2024-01-04:
Could you post the log of errors that you're seeing?

matisTopPath, 2024-01-05:
@miek, the error log,  I try to install luna on pi4 and ubuntu 22.04 but it always shows this error. : (

dev@dev:~/luna $ sudo python3 applets/interactive-test.py
`
Traceback (most recent call last):
  File "/home/dev/luna/applets/interactive-test.py", line 291, in <module>
    tester = top_level_cli(InteractiveSelftest)
             ^^^^^^^^^^^^^^^^^^^^^^^^^^^^^^^^^^
  File "/usr/local/lib/python3.11/dist-packages/luna/__init__.py", line 93, in top_level_cli
    platform = get_appropriate_platform()
               ^^^^^^^^^^^^^^^^^^^^^^^^^^
  File "/usr/local/lib/python3.11/dist-packages/luna/gateware/platform/__init__.py", line 100, in get_appropriate_platform
    platform = PLATFORM_FOR_REVISION[version]()
               ~~~~~~~~~~~~~~~~~~~~~^^^^^^^^^
KeyError: (1, 3)`

martinling, 2024-06-21:
This was happening because there wasn't a platform definition in the package for r1.3 boards.

Several things have changed since this issue was raised:
- The LUNA hardware design has been [renamed to Cynthion](https://www.crowdsupply.com/great-scott-gadgets/luna/updates/renaming-luna-hardware-to-cynthion).
- Platform definitions are no longer part of the LUNA package, they're maintained in other packages/repositories.
- Platforms for Cynthion r1.3 and all other board versions are now in the [cynthion](https://github.com/greatscottgadgets/cynthion) package.

If you install the `cynthion` package from the repository linked above, everything should work now.

Closed 2024-06-21.

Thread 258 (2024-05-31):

[DOC] please give example how to run luna/examples

hstarmans, 2024-05-31:
Thank for your effort and keeping this repo up to date,  I get several warning when using code from the repo and I am not sure how to use it anymore.
How do I run the blinky test?
I now do the following
```python
git clone https://github.com/greatscottgadgets/luna.git
cd luna/
python3 -m venv .venv
source .venv/bin/activate
pip install .
pip install cynthion
pip install git+https://github.com/amaranth-lang/amaranth-boards
pip install yowasp-nextpnr-ecp5
pip install yowasp-yosys
export NEXTPNR_ECP5=yowasp-nextpnr-ecp5
export ECPPACK=yowasp-ecppack
export YOSYS=yowasp-yosys
export LUNA_PLATFORM=cynthion.gateware.platform.cynthion_r0_4:CynthionPlatformRev0D4
python examples/blinky/blinky.py --dry-run
```
This fails, also for more recent boards.
```
INFO    | __init__    | Building for Cynthion r0.4...
ERROR: Module `\SGSR' referenced in module `\top.cd_sync' in cell `\U$$2' is not part of the design.
Traceback (most recent call last):
  File "/home/hstarmans/python/luna/examples/blinky/blinky.py", line 41, in <module>
    top_level_cli(Blinky)
  File "/home/hstarmans/python/luna/.venv/lib/python3.10/site-packages/luna/__init__.py", line 113, in top_level_cli
    products = platform.build(fragment,
  File "/home/hstarmans/python/luna/.venv/lib/python3.10/site-packages/amaranth/build/plat.py", line 109, in build
    products = plan.execute_local(build_dir)
  File "/home/hstarmans/python/luna/.venv/lib/python3.10/site-packages/amaranth/build/run.py", line 104, in execute_local
    subprocess.check_call(["sh", f"{self.script}.sh"],
  File "/usr/lib/python3.10/subprocess.py", line 369, in check_call
    raise CalledProcessError(retcode, cmd)
subprocess.CalledProcessError: Command '['sh', 'build_top.sh']' returned non-zero exit status 1.
```
Debug_spi seems still broken https://github.com/greatscottgadgets/luna/issues/101
```
INFO    | __init__    | Building for Cynthion r0.4...
/home/hstarmans/python/luna/.venv/lib/python3.10/site-packages/luna/gateware/utils/cdc.py:40: DriverConflict: Signal '(sig output__sdo__o)' is driven from multiple fragments: top, top.<unnamed #3>; hierarchy will be flattened
  output = Record.like(signal)
ERROR: Module `\SGSR' referenced in module `\top.cd_sync' in cell `\U$$2' is not part of the design.
Traceback (most recent call last):
``

miek, 2024-06-06:
I couldn't reproduce the issue when running the commands you posted:
```
INFO    | __init__    | Building for Cynthion r0.4...
Preparing to run yowasp-yosys. This might take a while...
Preparing to run yowasp-nextpnr-ecp5. This might take a while...
Preparing to run yowasp-ecppack. This might take a while...
INFO    | __init__    | Build complete.
```

Could try running `blinky.py` again with `AMARANTH_verbose=1` and post the output?

Closed 2025-04-23.

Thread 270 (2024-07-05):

AttributeError: 'Signal' object has no attribute 'o'

retif, 2024-07-05:
code version: a87888ea72f806f05660aa1a4dd336fc5d80a6f2

```
Traceback (most recent call last):
  File "/home/oleks/projects/orbtrace/./orbtrace_builder.py", line 112, in <module>
    main()
  File "/home/oleks/projects/orbtrace/./orbtrace_builder.py", line 101, in main
    builder.build(**trellis_argdict(args), run=args.build)
  File "/home/oleks/projects/litex/litex/litex/soc/integration/builder.py", line 373, in build
    self.soc.finalize()
  File "/home/oleks/projects/litex/litex/litex/soc/integration/soc.py", line 1477, in finalize
    Module.finalize(self)
  File "/home/oleks/projects/litex/migen/migen/fhdl/module.py", line 156, in finalize
    subfragments = self._collect_submodules()
                   ^^^^^^^^^^^^^^^^^^^^^^^^^^
  File "/home/oleks/projects/litex/migen/migen/fhdl/module.py", line 149, in _collect_submodules
    r.append((name, submodule.get_fragment()))
                    ^^^^^^^^^^^^^^^^^^^^^^^^
  File "/home/oleks/projects/litex/migen/migen/fhdl/module.py", line 102, in get_fragment
    self.finalize()
  File "/home/oleks/projects/litex/migen/migen/fhdl/module.py", line 157, in finalize
    self.do_finalize(*args, **kwargs)
  File "/home/oleks/projects/orbtrace/orbtrace/amaranth_glue/wrapper.py", line 84, in do_finalize
    f.write(self.generate_verilog())
            ^^^^^^^^^^^^^^^^^^^^^^^
  File "/home/oleks/projects/orbtrace/orbtrace/amaranth_glue/wrapper.py", line 61, in generate_verilog
    fragment = ir.Fragment.get(self.m, None).prepare(ports = ports)
               ^^^^^^^^^^^^^^^^^^^^^^^^^^^^^
  File "/home/oleks/toolchains/oss-cad-suite-20240705/lib/python3.11/site-packages/amaranth/hdl/ir.py", line 42, in get
    new_obj = obj.elaborate(platform)
              ^^^^^^^^^^^^^^^^^^^^^^^
  File "/home/oleks/toolchains/oss-cad-suite-20240705/lib/python3.11/site-packages/amaranth/hdl/dsl.py", line 562, in elaborate
    fragment.add_subfragment(Fragment.get(submodule, platform), None)
                             ^^^^^^^^^^^^^^^^^^^^^^^^^^^^^^^^^
  File "/home/oleks/toolchains/oss-cad-suite-20240705/lib/python3.11/site-packages/amaranth/hdl/ir.py", line 42, in get
    new_obj = obj.elaborate(platform)
              ^^^^^^^^^^^^^^^^^^^^^^^
  File "/home/oleks/toolchains/oss-cad-suite-20240705/lib/python3.11/site-packages/amaranth/hdl/dsl.py", line 560, in elaborate
    fragment.add_subfragment(Fragment.get(self._named_submodules[name], platform), name)
                             ^^^^^^^^^^^^^^^^^^^^^^^^^^^^^^^^^^^^^^^^^^^^^^^^^^^^
  File "/home/oleks/toolchains/oss-cad-suite-20240705/lib/python3.11/site-packages/amaranth/hdl/ir.py", line 42, in get
    new_obj = obj.elaborate(platform)
              ^^^^^^^^^^^^^^^^^^^^^^^
  File "/home/oleks/toolchains/oss-cad-suite-20240705/lib/python3.11/site-packages/luna/gateware/interface/ulpi.py", line 857, in elaborate
    m.d.comb += self.ulpi.rst.o.eq(ResetSignal(raw_clock_domain)),
                ^^^^^^^^^^^^^^^
AttributeError: 'Signal' object has no attribute 'o'
```

What this error could mean?

martinling, 2024-07-05:
This is to do with some changes in Amaranth and LUNA.

There was a lot of code that used to pass around `Pin` objects (which have `.o` for output signal and other attributes), which has been changed to pass `Signal` objects instead, to maintain compatibility with newer Amaranth versions.

The main change on the LUNA side was #219.

However, there's still some places where things aren't quite right, as I ran into in https://github.com/greatscottgadgets/cynthion/pull/101.

This needs some further investigation.

miek, 2024-07-05:
While it's similar to that issue I'm not sure that's what's going on here. It looks like you're using the version of Amaranth included in the OSS CAD suite, which will be 0.5.0 or newer and is not yet supported by LUNA. Also the LUNA tag you've picked is very old and doesn't work with any recent version of Amaranth.

None of this should be an issue though, since orbtrace includes all the correct versions of the dependencies it needs and it shouldn't be pulling from other paths. If you're building orbtrace from git, you need to be careful to check out the submodules too (with `git submodule update --init --recursive`).

retif, 2024-07-05:
@miek you absolutely right, thanks! After making `git submodule update` it works ok, thank you very much for pointing out.

@martinling sorry for bothering, closing the issue

Closed 2024-07-05.

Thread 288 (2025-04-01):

ERROR: PLL 'car.pll' clock input 'clk12_0__i' can only drive PLL

YusufCelik, 2025-04-01:
So, I designed my own pcb with an ice40up5k  to test the waters with LUNA USB according to known working designs (Upduino, TinyFpga, FOMU, etc.). To make life easier I decided on using a 12mhz external clk:

`  Resource("clk12", 0, Pins("35", dir="i"),
                 Clock(12e6)),`

In my clock domain generator code, I have the following:

`    def elaborate(self, platform):
        m = Module()

        # Request the external 12 MHz clock pin
        clk12 = platform.request("clk12")

        # Create the domains
        m.domains.usb = ClockDomain()
        m.domains.usb_io = ClockDomain()
        m.domains.fast = ClockDomain()

        platform.lookup(platform.default_clk).attrs['GLOBAL'] = False

        clk48 = Signal()

        m.submodules.pll = Instance("SB_PLL40_PAD",
                                    i_PACKAGEPIN=clk12.i,
                                    i_RESETB=Const(1),
                                    i_BYPASS=Const(0),

                                    o_PLLOUTCORE=clk48,

                                    p_FEEDBACK_PATH="SIMPLE",
                                    p_DIVR=0,
                                    p_DIVF=63,
                                    p_DIVQ=4,
                                    p_FILTER_RANGE=4
                                    )

        platform.add_clock_constraint(clk48, 48e6)

        m.d.comb += [
            ClockSignal("usb")     .eq(clk12.i),
            ClockSignal("usb_io")  .eq(clk48),
            ClockSignal("fast")    .eq(clk48)
        ]

        return m`

But I get the error: ERROR: PLL 'car.pll' clock input 'clk12_0__i' can only drive PLL

Apparently I cannot wire clk12 directly to the usb domain since it is already driving the PLL? Any tips how I can resolve this?

miek, 2025-04-01:
I'm not too familiar with the restrictions on ice40 but, checking a couple of the other examples, it looks like you can either use `SB_PLL40_CORE` (if your input is on the upper bank) or use `SB_PLL40_2F_PAD` for two PLL outputs.

https://github.com/greatscottgadgets/luna-boards/blob/main/luna_boards/fomu.py#L48
https://github.com/greatscottgadgets/luna-boards/blob/main/luna_boards/icebreaker.py#L53

YusufCelik, 2025-04-01:
Thanks! Would you believe it, I looked at the same references you shared and could not get it working.
Moreover, I do not have the official toolchain IDE of Lattice to have some wizard guide me.
Nevertheless, I tried again, and it worked (device enumerates)! For posterity I will post a working example here (since the underlying Amaranth syntax seems to also have changed in relation to the current board examples--it seems):

```
     m.submodules.pll = Instance("SB_PLL40_2F_PAD",
                                    i_PACKAGEPIN=platform.request("clk12").i,
                                    i_RESETB=Const(1),
                                    i_BYPASS=Const(0),

                                    o_PLLOUTGLOBALA=clk48,
                                    o_PLLOUTGLOBALB=clk12,

                                    # Create a 48 MHz PLL clock...
                                    p_FEEDBACK_PATH="SIMPLE",
                                    p_PLLOUT_SELECT_PORTA="GENCLK",
                                    p_PLLOUT_SELECT_PORTB="SHIFTREG_0deg",
                                    p_DIVR=0,
                                    p_DIVF=63,
                                    p_DIVQ=4,
                                    p_FILTER_RANGE=4,
                                    )

```

YusufCelik, 2025-04-02:
Closing this, since everything works in order. I am having a blast at the moment working through the examples. Able to write and verify data over USB.

Closed 2025-04-02.

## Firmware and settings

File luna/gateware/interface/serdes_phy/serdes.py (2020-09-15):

#
# This file is part of LUNA.
#
# Copyright (c) 2020 Great Scott Gadgets <info@greatscottgadgets.com>
# Copyright (c) 2020 Florent Kermarrec <florent@enjoy-digital.fr>
#
# Code based on ``litex`` and ``usb3_pipe``.
# SPDX-License-Identifier: BSD-3-Clause
""" Abstract SerDes interfacing code.

See also the FPGA family-specific SerDes backends located in the `backends` subfolder.
"""

import unittest

from nmigen import *
from nmigen.lib.cdc  import FFSynchronizer, PulseSynchronizer, ResetSynchronizer
from nmigen.lib.fifo import AsyncFIFOBuffered
from nmigen.hdl.ast  import Past

from ...test.utils import LunaGatewareTestCase, sync_test_case
from ...usb.stream import USBRawSuperSpeedStream

from ...usb.usb3.physical.coding import K, COM, SKP


#
# Receiver gateware
#

class ReceiverGearbox(Elaboratable):
    """ Simple rate-halving gearbox for our receive path.

    Designed specifically for our receive path; always halves the frequency of the input;
    and ignores "readiness", as the SerDes is always constantly producing output.

    If :attr:``output_domain`` is provided, clock domain crossing is handled automatically.

    Attributes
    ----------
    sink: input stream
        The full-rate stream to be geared down.
    source: output stream
        The half-rate stream, post-gearing.

    Parameters
    ----------
    words_in: int, optional
        The number of words of data to be processed at once; each word includes one byte of data and one
        bit of control. Output will always be twice this value. Defaults to 2.
    input_domain: str
        The name of the clock domain that our :attr:``sink`` resides in. Defaults to `rx`.
    output_domain: str, or None
        The name of the clock domain that our :attr:``source`` resides in. If not provided, no CDC
        hardware will be generated.
    """

    def __init__(self, words_in=2, input_domain="rx", output_domain=None):
        self._flip_bytes      = True
        self._words_in        = words_in
        self._data_bits_in    = words_in * 8
        self._ctrl_bits_in    = words_in
        self._input_domain    = input_domain
        self._output_domain   = output_domain if output_domain else input_domain

        #
        # I/O port
        #
        self.sink   = USBRawSuperSpeedStream(payload_words=words_in)
        self.source = USBRawSuperSpeedStream(payload_words=words_in * 2)


    def elaborate(self, platform):
        m = Module()

        # Buffer our stream inputs here to improve timing.
        stream_in_data  = Signal.like(self.sink.data)
        stream_in_ctrl  = Signal.like(self.sink.ctrl)
        stream_in_valid = Signal.like(self.sink.valid)
        m.d.sync += [
            stream_in_data   .eq(self.sink.data),
            stream_in_ctrl   .eq(self.sink.ctrl),
            stream_in_valid  .eq(self.sink.valid),
        ]

        # Aliases.
        stream_in  = self.sink
        if self._flip_bytes:
            stream_in_data = stream_in.data.rotate_right((self._words_in // 2) * 8)
            stream_in_ctrl = stream_in.ctrl.rotate_right(self._words_in // 2)
        else:
            stream_in_data = stream_in.data
            stream_in_ctrl = stream_in.ctrl


        # If our output domain is the same as our input domain, we'll directly drive our output stream.
        # Otherwise, we'll drive an internal signal; and then cross that into our output domain.
        if self._output_domain == self._input_domain:
            stream_out = self.source
        else:
            stream_out = USBRawSuperSpeedStream()


        # Create proxies that allow us access to the upper and lower halves of our output data stream.
        data_out_halves = Array(stream_out.data.word_select(i, self._data_bits_in) for i in range(2))
        ctrl_out_halves = Array(stream_out.ctrl.word_select(i, self._ctrl_bits_in) for i in range(2))

        # Word select -- selects whether we're targeting the upper or lower half of the output word.
        # Toggles every input-domain cycle.
        targeting_upper_half = Signal(reset=1 if self._flip_bytes else 0)
        m.d.sync += targeting_upper_half.eq(~targeting_upper_half)

        # Pass through our data and control every cycle.
        m.d.sync += [
            data_out_halves[targeting_upper_half]  .eq(stream_in_data),
            ctrl_out_halves[targeting_upper_half]  .eq(stream_in_ctrl),
        ]

        # Set our valid signal high only if both the current and previously captured word are valid.
        m.d.comb += [
            stream_out.valid  .eq(stream_in.valid & Past(stream_in.valid, domain=self._input_domain))
        ]

        if self._input_domain != self._output_domain:
            in_domain_signals  = Cat(
                stream_out.data,
                stream_out.ctrl,
                stream_out.valid
            )
            out_domain_signals = Cat(
                self.source.data,
                self.source.ctrl,
                self.source.valid
            )

            # Create our async FIFO...
            m.submodules.cdc = fifo = AsyncFIFOBuffered(
                width=len(in_domain_signals),
                depth=8,
                w_domain="sync",
                r_domain=self._output_domain
            )

            m.d.comb += [
                # ... fill it from our in-domain stream...
                fifo.w_data             .eq(in_domain_signals),
                fifo.w_en               .eq(targeting_upper_half),

                # ... and output it into our output stream.
                out_domain_signals      .eq(fifo.r_data),
                self.source.valid       .eq(fifo.r_level > 2),
                fifo.r_en               .eq(1),
            ]


        # If our source domain isn't `sync`, translate `sync` to the proper domain name.
        if self._input_domain != "sync":
            m = DomainRenamer({'sync': self._input_domain})(m)

        return m


class ReceiverSkipRemover(Elaboratable):
    """ Clock Tolerance Compensation (CTC) Skip remover.

    SKP Ordered Sets are inserted in the stream for clock compensation between partners with an
    average of 1 SKP Ordered Set every 354 symbols. This module removes SKP Ordered Sets from
    the RX stream.
    """

    def __init__(self):

        #
        # I/O port
        #
        self.sink   = USBRawSuperSpeedStream()
        self.source = USBRawSuperSpeedStream()
        self.skip   = Signal()


    def elaborate(self, platform):
        m = Module()

        sink   = self.sink
        source = self.source

        #
        # Find SKP symbols
        #
        skp = Signal(4)
        for i in range(4):
            m.d.comb += skp[i].eq(sink.ctrl[i] & (sink.data[8*i:8*(i+1)] == SKP.value))
        m.d.comb += self.skip.eq(self.sink.valid & self.sink.ready & (skp != 0))

        #
        # Select valid Data/Ctrl fragments
        #
        frag_data  = Signal(32)
        frag_ctrl  = Signal(4)
        frag_bytes = Signal(3)

        with m.Switch(skp):
            for i in range(2**4):
                with m.Case(i):

                    datas = []
                    ctrls = []

                    for j in range(4):
                        if (i & 2**j) == 0:
                            datas.append(sink.data[8*j:8*(j+1)])
                            ctrls.append(sink.ctrl[1*j:1*(j+1)])

                    m.d.comb += [
                        frag_data.eq(Cat(*datas) if len(datas) else 0),
                        frag_ctrl.eq(Cat(*ctrls) if len(ctrls) else 0),
                        frag_bytes.eq(len(ctrls)),
                    ]

        # Store Data/Ctrl in a 64/8-bit Shift Register ---------------------------------------------
        sr_data  = Signal(64)
        sr_ctrl  = Signal(8)
        sr_bytes = Signal(4)


        m.d.comb += sink.ready.eq(sr_bytes <= 7)


        with m.If(sink.valid & sink.ready):

            with m.If(source.valid & source.ready):
                m.d.ss += sr_bytes.eq(sr_bytes + frag_bytes - 4)
            with m.Else():
                m.d.ss += sr_bytes.eq(sr_bytes + frag_bytes)

            with m.Switch(frag_bytes):

                with m.Case(0):
                    m.d.ss += [
                        sr_data.eq(sr_data),
                        sr_ctrl.eq(sr_ctrl),
                    ]

                for i in range(1, 5):
                    with m.Case(i):
                        m.d.ss += [
                            sr_data.eq(Cat(sr_data[8*i:], frag_data[0:8*i])),
                            sr_ctrl.eq(Cat(sr_ctrl[1*i:], frag_ctrl[0:1*i])),
                        ]


        with m.Elif(source.valid & source.ready):
            m.d.ss += sr_bytes.eq(sr_bytes - 4)


        # Output Data/Ctrl when there is a full 32/4-bit word --------------------------------------
        m.d.comb += source.valid.eq(sr_bytes >= 4)
        cases = {}

        with m.Switch(sr_bytes):
            for i in range(4, 8):
                with m.Case(i):
                    m.d.comb += [
                        source.data.eq(sr_data[8*(8-i):8*(8-i+4)]),
                        source.ctrl.eq(sr_ctrl[1*(8-i):1*(8-i+4)]),
                    ]

        return m




class RxWordAligner(Elaboratable):
    """ Receiver word alignment.

    Uses the location of COM signals in the data stream to re-position data so that the
    relevant commas always fall in the data's MSB (big endian).
    """

    def __init__(self):
        self._is_big_endian = True

        #
        # I/O port
        #
        self.align  = Signal()
        self.sink   = USBRawSuperSpeedStream()
        self.source = USBRawSuperSpeedStream()

        # Debug signals
        self.alignment_offset = Signal(range(4))


    def elaborate(self, platform):
        m = Module()

        # Aliases
        stream_in   = self.sink
        stream_out  = self.source

        # Values from previous cycles.
        previous_data = Past(stream_in.data, domain="ss")
        previous_ctrl = Past(stream_in.ctrl, domain="ss")

        # Alignment register: stores how many words the data must be shifted by in order to
        # have correctly aligned data.
        shift_to_apply = Signal(range(4))

        #
        # Alignment detector.
        #

        # Apply new alignments only if we're the first seen COM (since USB3 packets can contain multiple
        # consecutive COMs), and if alignment is enabled.
        following_data_byte = (previous_ctrl == 0)
        with m.If(self.align & following_data_byte):

            # Detect any alignment markers by looking for a COM signal in any of the four positions.
            for i in reversed(range(4)):
                data_matches = (stream_in.data.word_select(i, 8) == COM.value)
                ctrl_matches = stream_in.ctrl[i]

                # If the current position has a comma in it, mark this as our alignment position;
                # and compute how many times we'll need to rotate our data _right_ in order to achieve
                # proper alignment.
                with m.If(data_matches & ctrl_matches):
                    if self._is_big_endian:
                        m.d.ss += [
                            shift_to_apply    .eq(3 - i),
                            stream_out.valid  .eq(shift_to_apply == (3 - i))
                        ]
                    else:
                        m.d.ss += [
                            shift_to_apply  .eq(i),
                            stream_out.valid.eq(shift_to_apply == i)
                        ]


        #
        # Aligner.
        #

        # To align our data, we'll create a conglomeration of two consecutive words;
        # and then select the chunk between those words that has the alignment correct.
        # (These words should always be in chronological order; so we'll need different
        # orders for big endian and little endian output.)
        if self._is_big_endian:
            data = Cat(stream_in.data, previous_data)
            ctrl = Cat(stream_in.ctrl, previous_ctrl)
        else:
            data = Cat(previous_data, stream_in.data)
            ctrl = Cat(previous_ctrl, stream_in.ctrl)

        # Create two multiplexers that allow us to select from each of our four possible
        # alignments...
        shifted_data_slices = Array(data[8*i:] for i in range(4))
        shifted_ctrl_slices = Array(ctrl[i:]   for i in range(4))

        # ... and output our data accordingly.
        m.d.ss += [
            stream_out.data  .eq(shifted_data_slices[shift_to_apply]),
            stream_out.ctrl  .eq(shifted_ctrl_slices[shift_to_apply]),

            # Debug output.
            self.alignment_offset.eq(shift_to_apply)
        ]

        return m


class RxDatapath(Elaboratable):
    """RX Datapath

    This module realizes the:
    - Data-width adaptation (from transceiver's data-width to 32-bit).
    - Clock domain crossing (from transceiver's RX clock to system clock).
    - Clock compensation (SKP removing).
    - Words alignment.
    """
    def __init__(self, clock_domain="rx", buffer_clock_domain="fast", output_clock_domain="ss"):
        self._clock_domain        = clock_domain
        self._buffer_clock_domain = buffer_clock_domain
        self._output_clock_domain = output_clock_domain

        #
        # I/O port
        #
        self.align  = Signal()
        self.sink   = USBRawSuperSpeedStream(payload_words=2)
        self.source = USBRawSuperSpeedStream(payload_words=4)

        # Debug signals
        self.alignment_offset = Signal(range(4))


    def elaborate(self, platfrom):
        m = Module()

        #
        # 1:2 Gearing (and clock domain crossing).
        #
        m.submodules.gearing = gearing = ReceiverGearbox(
            input_domain  = self._clock_domain,
            output_domain = "ss"
        )
        m.d.comb += gearing.sink.stream_eq(self.sink)

        #
        # Clock tolerance compensation.
        #
        #m.submodules.skip_remover = skip_remover = ReceiverSkipRemover()
        #m.d.comb += skip_remover.sink.stream_eq(gearing.source)

        #
        # Word aligner.
        #
        m.submodules.word_aligner = word_aligner = RxWordAligner()
        m.d.comb += [
            #  Core outputs
            word_aligner.align      .eq(self.align),
            word_aligner.sink       .stream_eq(gearing.source),

            # Debug output.
            self.alignment_offset   .eq(word_aligner.alignment_offset)

        ]

        #
        # Final output.
        #
        m.d.comb += self.source.stream_eq(word_aligner.source)

        return m


#
# Transmitter gateware
#


class TransmitterGearbox(Elaboratable):
    """ Simple rate-doubling gearbox for our transmit path.

    Designed specifically for our transmit path; always doubles the frequency of the input;
    and ignores "readiness", as the SerDes is always constantly producing output.

    If :attr:``output_domain`` is provided, clock domain crossing is handled automatically.

    Attributes
    ----------
    sink: input stream
        The single-rate stream to be geared up.
    source: output stream
        The double-rate stream, post-gearing.

    Parameters
    ----------
    words_in: int, optional
        The number of words of data to be processed at once; each word includes one byte of data and one
        bit of control. Output will always be twice this value. Defaults to 4.
    output_domain: str
        The name of the clock domain that our :attr:``source`` resides in. Defaults to `tx`.
    input_domain: str, or None
        The name of the clock domain that our :attr:``sink`` resides in. If not provided, no CDC
        hardware will be generated.
    """

    def __init__(self, words_in=4, output_domain="tx", input_domain=None):
        self._ratio           = 2
        self._flip_bytes      = True
        self._words_in        = words_in
        self._words_out       = words_in // 2
        self._output_domain   = output_domain
        self._input_domain    = input_domain if input_domain else output_domain

        #
        # I/O port
        #
        self.sink   = USBRawSuperSpeedStream(payload_words=self._words_in)
        self.source = USBRawSuperSpeedStream(payload_words=self._words_out)


    def elaborate(self, platform):
        m = Module()

        # If we're receiving data from an domain other than our output domain,
        # cross it over nicely.
        if self._input_domain != self._output_domain:
            stream_in = USBRawSuperSpeedStream(payload_words=self._words_in)
            in_domain_signals  = Cat(
                self.sink.data,
                self.sink.ctrl,
            )
            out_domain_signals = Cat(
                stream_in.data,
                stream_in.ctrl,
            )

            # Advance our FIFO only ever other cycle.
            advance_fifo = Signal()
            m.d.tx += advance_fifo.eq(~advance_fifo)

            # Create our async FIFO...
            m.submodules.cdc = fifo = AsyncFIFOBuffered(
                width=len(in_domain_signals),
                depth=8,
                w_domain=self._input_domain,
                r_domain="tx"
            )

            m.d.comb += [
                # ... fill it from our in-domain stream...
                fifo.w_data             .eq(in_domain_signals),
                fifo.w_en               .eq(1),
                self.sink.ready         .eq(1),

                # ... and output it into our output stream.
                out_domain_signals      .eq(fifo.r_data),
                stream_in.valid         .eq(fifo.r_rdy),
                fifo.r_en               .eq(advance_fifo),
            ]

        # Otherwise, use our data-stream directly.
        else:
            stream_in = self.sink
            m.d.comb += self.sink.ready.eq(1)


        # Word select -- selects whether we're targeting the upper or lower half of the input word.
        # Toggles every input-domain cycle.
        next_half_targeted   = Signal()
        targeting_upper_half = Signal()

        # If our data has just changed, we should always be targeting the upper word.
        # This "locks" us to the data's changes.
        data_changed = stream_in.data != Past(stream_in.data, domain="tx")
        ctrl_changed = stream_in.ctrl != Past(stream_in.ctrl, domain="tx")
        with m.If(data_changed | ctrl_changed):
            m.d.comb += targeting_upper_half  .eq(1 if self._flip_bytes else 0)
            m.d.tx   += next_half_targeted    .eq(0 if self._flip_bytes else 1)
        with m.Else():
            m.d.comb += targeting_upper_half  .eq(next_half_targeted)
            m.d.tx   += next_half_targeted    .eq(~next_half_targeted)


        # If we're flipping the bytes in our output stream (e.g. to maintain endianness),
        # create a flipped version; otherwise, use our output stream directly.
        stream_out = self.source

        # Create proxies that allow us access to the upper and lower halves of our input data stream.
        data_in_halves = Array(stream_in.data.word_select(i, len(stream_in.data) // 2) for i in range(2))
        ctrl_in_halves = Array(stream_in.ctrl.word_select(i, len(stream_in.ctrl) // 2) for i in range(2))

        # Pass through our data and control every cycle.
        # This is registered to loosen timing.
        if self._flip_bytes:
            stream_out_data = data_in_halves[targeting_upper_half]
            stream_out_ctrl = ctrl_in_halves[targeting_upper_half]
            m.d.tx += [
                stream_out.data  .eq(stream_out_data.rotate_right(len(stream_out_data) // 2)),
                stream_out.ctrl  .eq(stream_out_ctrl.rotate_right(len(stream_out_ctrl) // 2)),
                stream_out.valid .eq(1),
            ]
        else:
            m.d.tx += [
                stream_out.data  .eq(data_in_halves[targeting_upper_half]),
                stream_out.ctrl  .eq(ctrl_in_halves[targeting_upper_half]),
                stream_out.valid .eq(1),
            ]

        # If our output domain isn't `sync`, translate `sync` to the proper domain name.
        if self._output_domain != "tx":
            m = DomainRenamer({'tx': self._output_domain})(m)

        return m


class TransmitterGearboxTest(LunaGatewareTestCase):
    FRAGMENT_UNDER_TEST = TransmitterGearbox
    FRAGMENT_ARGUMENTS = {'output_domain': 'sync'}

    @sync_test_case
    def test_basic_gearbox(self):
        dut    = self.dut
        sink   = dut.sink
        source = dut.source

        # If we start off with our stream presenting COM, 0xFF, 0x17, 0xC0.
        yield sink.data.eq(0xBCFF17C0)
        yield sink.ctrl.eq(0b1000)

        # After a two-cycle pipeline delay, we should see the first word on our output...
        yield from self.advance_cycles(2)
        self.assertEqual((yield source.data), 0xFFBC)
        self.assertEqual((yield source.ctrl), 0b01)
        yield sink.data.eq(0x14B2E702)
        yield sink.ctrl.eq(0b0000)

        # ... followed by the second...
        yield from self.advance_cycles(1)
        self.assertEqual((yield source.data), 0xC017)
        self.assertEqual((yield source.ctrl), 0b00)

        # ... and our data should continue changing with the input.
        yield from self.advance_cycles(1)
        self.assertEqual((yield source.data), 0xB214)
        self.assertEqual((yield source.ctrl), 0b00)
        yield from self.advance_cycles(1)
        self.assertEqual((yield source.data), 0x02E7)
        self.assertEqual((yield source.ctrl), 0b00)





# RXErrorSubstitution (6.3.5) ----------------------------------------------------------------------
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

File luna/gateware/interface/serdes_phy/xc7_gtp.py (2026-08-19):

#
# This file is part of LUNA.
#
# Copyright (c) 2020 Great Scott Gadgets <info@greatscottgadgets.com>
# Copyright (c) 2020 Florent Kermarrec <florent@enjoy-digital.fr>
#
# Code based in part on ``litex`` and ``liteiclink``.
# SPDX-License-Identifier: BSD-3-Clause
""" Soft PIPE backend for the Xilinx 7 Series GTP transceivers. """

from amaranth import *
from amaranth.lib.cdc import FFSynchronizer


from .xc7           import DRPInterface, DRPArbiter, DRPFieldController
from .xc7           import GTResetDeferrer, GTPRXPMAResetWorkaround, GTOOBClockDivider
from .lfps         import LFPSSquareWaveGenerator, LFPSSquareWaveDetector
from ..pipe        import PIPEInterface


Open = Signal


class GTPQuadPLL(Elaboratable):
    def __init__(self, refclk, refclk_freq, linerate, channel=0):
        assert channel in [0, 1]
        self.channel     = channel

        self._refclk      = refclk
        self._refclk_freq = refclk_freq
        self._linerate    = linerate

        self.config  = self.compute_config(refclk_freq, linerate)

        #
        # I/O ports
        #
        self.clk     = Signal()
        self.refclk  = Signal()
        self.reset   = Signal()
        self.lock    = Signal()
        self.drp     = DRPInterface()


    def elaborate(self, platform):
        gtpe2_params = dict(
            # Common Block Attributes
            p_BIAS_CFG          = 0x0000000000050001,
            p_COMMON_CFG        = 0x00000000,

            # PLL Attributes
            p_PLL_CLKOUT_CFG    = 0x00,
            p_PLLx_CFG          = 0x01F03DC,
            p_PLLx_DMON_CFG     = 0b0,
            p_PLLx_FBDIV        = self.config["n2"],
            p_PLLx_FBDIV_45     = self.config["n1"],
            p_PLLx_INIT_CFG     = 0x00001E,
            p_PLLx_LOCK_CFG     = 0x1E8,
            p_PLLx_REFCLK_DIV   = self.config["m"],

            # Common Block - Dynamic Reconfiguration Port
            i_DRPCLK            = ClockSignal("ss"),
            i_DRPADDR           = self.drp.addr,
            i_DRPDI             = self.drp.di,
            o_DRPDO             = self.drp.do,
            i_DRPWE             = self.drp.we,
            i_DRPEN             = self.drp.en,
            o_DRPRDY            = self.drp.rdy,

            # Common Block - Clocking Ports
            i_GTREFCLK0         = self._refclk,
            o_PLLxOUTCLK        = self.clk,
            o_PLLxOUTREFCLK     = self.refclk,

            # Common Block - PLL Ports
            o_PLLxLOCK          = self.lock,
            i_PLLxLOCKEN        = 1,
            i_PLLxPD            = 0,
            i_PLLxREFCLKSEL     = 0b001,
            i_PLLxRESET         = self.reset,

            i_PLLyPD            = 1,

            # QPLL Ports
            i_BGBYPASSB         = 1,
            i_BGMONITORENB      = 1,
            i_BGPDB             = 1,
            i_BGRCALOVRD        = 0b11111,
            i_RCALENB           = 1,
        )

        if self.channel == 0:
            pll_x, pll_y = "PLL0", "PLL1"
        else:
            pll_x, pll_y = "PLL1", "PLL0"

        return Instance("GTPE2_COMMON", **{
            name.replace("PLLx", pll_x).replace("PLLy", pll_y): value
            for name, value in gtpe2_params.items()
        })


    @staticmethod
    def compute_config(refclk_freq, linerate):
        for n1 in 4, 5:
            for n2 in 1, 2, 3, 4, 5:
                for m in 1, 2:
                    vco_freq = refclk_freq*(n1*n2)/m
                    if 1.6e9 <= vco_freq <= 3.3e9:
                        for d in 1, 2, 4, 8, 16:
                            current_linerate = vco_freq*2/d
                            if current_linerate == linerate:
                                return {"n1": n1, "n2": n2, "m": m, "d": d,
                                        "vco_freq": vco_freq,
                                        "clkin": refclk_freq,
                                        "linerate": linerate}
        msg = "No config found for {:3.2f} MHz refclk / {:3.2f} Gbps linerate."
        raise ValueError(msg.format(refclk_freq/1e6, linerate/1e9))

    def __repr__(self):
        config = self.config
        r = """
GTPQuadPLL
==========
  overview:
  ---------
       +--------------------------------------------------+
       |                                                  |
       |            +---------------------------+ +-----+ |
       |   +-----+  | Phase Frequency Detector  | |     | |
CLKIN +----> /M  +-->       Charge Pump         +-> VCO +---> CLKOUT
       |   +-----+  |       Loop Filter         | |     | |
       |            +---------------------------+ +--+--+ |
       |              ^                              |    |
       |              |    +-------+    +-------+    |    |
       |              +----+  /N2  <----+  /N1  <----+    |
       |                   +-------+    +-------+         |
       +--------------------------------------------------+
                            +-------+
                   CLKOUT +->  2/D  +-> LINERATE
                            +-------+
  config:
  -------
    CLKIN    = {clkin}MHz
    CLKOUT   = CLKIN x (N1 x N2) / M = {clkin}MHz x ({n1} x {n2}) / {m}
             = {vco_freq}GHz
    LINERATE = CLKOUT x 2 / D = {vco_freq}GHz x 2 / {d}
             = {linerate}GHz
""".format(clkin    = config["clkin"]/1e6,
           n1       = config["n1"],
           n2       = config["n2"],
           m        = config["m"],
           vco_freq = config["vco_freq"]/1e9,
           d        = config["d"],
           linerate = config["linerate"]/1e9)
        return r
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

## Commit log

2019-10-17 luna: early: capture power network and start routing configuration section
    [fpga_configuration.sch, luna_rev0.kicad_pcb, luna_rev0.sch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]
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2019-10-21 rev0: clean up library references and backup files
    [debug_control_connections.sch, fpga_configuration.sch, host_side.sch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]
2019-10-21 rev0: throw the parts down so we can get starting routing
    [host_side.sch, luna_rev0.kicad_pcb, luna_rev0.sch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]
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2019-10-22 rev0: get most of the major routing done
    still needs power routing, length matching for the busses,
    and routing for the misc control stuff
    [debug_control_connections.sch, fpga_configuration.sch, host_side.sch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]
2019-10-22 rev0: shrink board outline to < 50mm x 50mm
    [luna_rev0.kicad_pcb]
2019-10-24 rev0: routing: get our routing significnatly more complete :)
    [host_side.sch, luna_rev0.kicad_pcb, luna_rev0.sch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]
2019-10-24 rev0: implement all of the routing except length matching
    [debug_control_connections.sch, luna_rev0.kicad_pcb, luna_rev0.sch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]
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2019-11-26 hw: pre r0.1: add models and update silkscreen / markings
    [luna_rev0.kicad_pcb]
2019-12-03 capture r0.1, as scheduled for fabiraction on nov26th
    [luna_rev0-B_Cu.gbl, luna_rev0-B_Mask.gbs, luna_rev0-B_Paste.gbp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]
2019-12-03 r0.1: fab: reduce paste pullback so copper and paste are 1:1
    [luna_rev0.kicad_pcb]
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2020-01-03 hardware: fix reversed FPGA leds, 1V1 regulator pinout, silk typo
    [luna_rev0.kicad_pcb, luna_rev0.sch, power_supplies.sch]
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2020-01-06 spi: rewrite gateware interface + fix apollo transmission issue
    [spi.py]
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2020-01-12 workflow: improve upload/flash/etc utilities; improve reset behavior
    [ecp5.py]
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2020-01-16 pre r0.2 -- minor improvements and debug fixes
    - add silkscreen connector diagrams
    - added test points for clock and voltage rails
    - moved SPI connectors for reduced via density (DFM)
    - added chip select for debug SPI
    [debug_control_connections.sch, fpga_configuration.sch, luna_rev0.kicad_pcb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]
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2020-01-18 SPI: improvements to SPI hardware and testing; and minor fixes
    [spi.py]
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2020-01-20 apollo.spi: fix debug SPI transactions longer than a buffer size
    [spi.py]
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2020-01-28 apollo.spi_flash: fix SPI flash passthrough
2020-01-31 gateware: clean up of module paths and CAR fixes
    domains are now properly held in reset until everything stabalizes
    [spi.py]
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2020-02-15 gateware.usb: fix analyzer test case to include bus turnaround cycles
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2020-03-15 apollo.spi: better messages when register-size autonegotation fails
    Closes #2.
    [spi.py]
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2020-04-20 dependencies: no longer require a particular pyvcd version
    We'll let nMigen assert this for us; and commit to being compatible with
    the version supported by nMigen. We'll likely want to specify specific versions
    when we cut releases.
2020-04-23 gateware.soc: add LED blinky to examples; and add missing volatile
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2020-05-20 hardware: update .gitignore, remove gerbers and other generated files
    [luna_rev0-B_Cu.gbl, luna_rev0-B_Mask.gbs, luna_rev0-B_Paste.gbp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]
2020-05-20 hardware: correct R3 footprint
    fix #11
    [luna_rev0.kicad_pcb, luna_rev0.sch]
2020-05-20 hardware: update capacitors in schematic
    Add parts that were in layout but were missing from schematic.
    Update schematic to better represent r0.2 as manufactured.
    fix #10
    [host_side.sch, luna_rev0.kicad_pcb, luna_rev0.sch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]
2020-05-20 hardware: Change U4 to match part number
    Update value and symbol name from TCR2EF11 to TCR2EE11.
    fix #12
    [luna_rev0.kicad_pcb, power_supplies.sch]
2020-05-20 hardware: normalize BOM fields
    make compatible with kicad-bom-scripts
    [debug_control_connections.sch, fpga_configuration.sch, host_side.sch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]
2020-05-20 hardware: correct outdated license notices
    [debug_control_connections.sch, fpga_configuration.sch, host_side.sch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]
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2020-05-20 hardware: correct TCR2EE11 symbol pin numbering
    [luna_rev0.kicad_pcb]
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2020-07-03 hardware: adopt OSHWA convention for SPI signal names
    https://www.oshwa.org/a-resolution-to-redefine-spi-signal-names
    [luna_rev0.kicad_pcb, luna_rev0.sch, right_side_indicators.sch]
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2020-07-12 Changed all uses of Rose, Fell, and Past to include which clock domain should be used for the history of samples. This avoid a problem where the main "sync" domain gets used despite a DomainRenamer b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
    [spi.py]
2020-07-18 gateware.*: fix use of whole Pin records and rework request_optional
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2020-07-27 gateware.devices: ACM: fix typo in interface number
    Correct from 0x02 (reserved) to 0x01 (AT modem).
    Fixes #32.
    [acm.py]
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2020-08-12 apollo: add support for programming Intel chips, and fix SVF playback
    [ecp5.py]
2020-08-14 gateware.platform: invert LEDResources to match hardware
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2020-09-06 gateware.debug: fix typo in USB ILA name
    [ila.py]
2020-09-14 BREAKING CHANGE: gateware.stream: fix the direction of connect
    This commit fixes an error in which .connect() was implemented opposite
    of the nMigen core .connect() for nMigen streams. This has been
    corrected; and in many cases .connect() has been replaced with
    .stream_eq(), which should hopefully be less confusing.
    [acm.py, ila.py]
2020-09-20 gateware.gateware_phy: fix functionality with 7-series devices
    Also fix a stray (harmless) bit on all platforms.
2020-09-30 gateware.usb3: add proper CTC and fix scrambler loss-of-sync
    [lfps.py]
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2020-10-15 gateware.usb3: fix several enumeration and transmission related issues
    - fix a race condition affecting transmit timing
    - don't realy on packets remaining word aligned; even if they do in
    practice
    - fix duplicate responses to GET_STATUS and GET_CONFIGURATION requests
    - adjust how zero-length packets are conveyed to the link-layer tx
    - update gtkwave debug filters
2020-10-16 gateware.usb3: fix issues with enumeration on Windows; fix most hubs
    [lfps.py]
2020-11-03 test.contrib: fix printing encoded data for enum values
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2020-12-15 fix typo in USB ILA name
    [ila.py]
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2021-01-13 hardware: replace Y1 DSC6001MI2A-060.0000 with SIT1602BC-73-33E-60.000000E
    [luna_rev0.kicad_pcb, luna_rev0.sch]
2021-01-13 hardware: do not populate C52
    Omitting C52 reduces ripple in the +3V3 supply.
    [power_supplies.sch]
2021-01-13 hardware: pull down PHY RESET pins instead of pulling them up
    [host_side.sch, luna_rev0.kicad_pcb, sideband_side.sch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]
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2021-01-13 hardware: clean up U3 input capacitors
    Remove C40 and C47. Move C6 closer to U3.
    [luna_rev0.kicad_pcb, power_supplies.sch]
2021-01-13 hardware: make R17, R19, R21 tolerance 5% not 0.1%
    [host_side.sch, sideband_side.sch, target_side.sch]
2021-01-13 hardware: change U10 from Cypress S27KS0641DPBHI020 to Winbond W956D8MBYA5I
    [luna_rev0.kicad_pcb, ram_section.sch]
2021-01-13 hardware: provide option to populate with 3.3 V HyperRAM
    [luna_rev0.kicad_pcb, power_supplies.sch]
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2021-01-13 hardware: replace U6 ATSAMD21 with ATSAMD11
    remove FORCE_RECOVERY button
    renumber button references
    remove FPGA connections to U6 and replace with test points:
    CS_DI
    FPGA_CONFIG_CLK
    FPGA_DONE
    FPGA_INIT
    DEBUG_SPI_MISO
    DEBUG_SPI_MOSI
    DEBUG_SPI_CLK
    DEBUG_SPI_CS
    [fpga_configuration.sch, host_side.sch, luna_rev0.kicad_pcb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]
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2021-01-13 hardware: change J3 part selection to Jing C42504
    Footprint is designed for Kycon KUSBXHT-SB-AS1N-B30-NF in order to fit a
    wide variety of compatible parts.
    [debug_control_connections.sch, fpga_configuration.sch, host_side.sch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]
2021-01-13 hardware: fix load switch oscillation by decreasing R1 and R2 values
    update load switch input and output capacitors
    add GND zone on In2.Cu under J3 data signals
    [luna_rev0.kicad_pcb, luna_rev0.sch]
2021-01-13 hardware: change micro USB connectors to Type-C (J1, J2, J4)
    Thanks for the footprint, Glasgow!
    [debug_control_connections.sch, fpga_configuration.sch, host_side.sch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]
2021-01-13 hardware: improve PHY ground/thermal connections (U8, U9, U11)
    [host_side.sch, luna_rev0.kicad_pcb, luna_rev0.sch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]
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2021-01-13 hardware: change U3 to AP7366-33W5-7 (3.3 V regulator)
    [debug_control_connections.sch, fpga_configuration.sch, host_side.sch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]
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2021-01-13 hardware: add ability to provide VBUS on Type-C target port (J4)
    [debug_control_connections.sch, fpga_configuration.sch, host_side.sch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]
2021-01-13 hardware: change load switches to AP22811 (U1, U12, U13)
    [luna_rev0.kicad_pcb, power_supplies.sch]
2021-01-13 hardware: change HyperRAM (U10) from 1.8V to 3.3V
    eliminate +1V8 supply
    [fpga_configuration.sch, host_side.sch, luna_rev0.kicad_pcb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]
2021-01-13 hardware: convert user i/o header (J7) to PMOD
    add more user i/o signals
    route LVDS pair to SMA connectors (J8, J9)
    [debug_control_connections.sch, fpga_configuration.sch, host_side.sch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]
2021-01-13 hardware: change 60 MHz oscillator (Y1) package
    3.2x2.5 mm package has lower price and wider availability of substitutions
    [debug_control_connections.sch, fpga_configuration.sch, host_side.sch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]
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2021-01-13 hardware: add indentations to board edge
    Enclosures and test jigs may now be designed that fit the PCB in only
    one orientation.
    [luna_rev0.kicad_pcb]
2021-01-13 hardware: add ability to measure TARGET_VBUS_C with ADC
    [debug_control_connections.sch, fpga_configuration.sch, host_side.sch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]
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2021-01-13 hardware: clear up ERC errors
    [clock_pmod.sch, host_side.sch, power_supplies.sch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]
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2021-01-13 hardware: add/restore missing 3D models
    [luna_rev0.kicad_pcb]
2021-01-13 hardware: add paste-in-hole to USB Type-C connectors (J1, J2, J4)
    [luna_rev0.kicad_pcb]
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2021-01-13 hardware: clarify schematic
    specify CC resistors as ±10% to hint that the spec requires it
    add resistance value to resistor networks
    give UART nets top-level names indicating JTAG functions
    change AP22811 values to AP22811A
    change PMOD to Pmod
    nudge FPGA_TMS trace to make it more bodgeable
    [clock_pmod.sch, fpga_configuration.sch, host_side.sch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]
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2021-01-13 hardware: clean up HyperRAM track clearances
    [luna_rev0.kicad_pcb]
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2021-01-13 hardware: add optional capacitors to some user i/o
    [luna_rev0.kicad_pcb, sideband_side.sch]
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2021-01-19 hardware: fix VBUS_A_TO_C_EN/VBUS_C_TO_A_EN labels
    [luna_rev0.kicad_pcb, luna_rev0.sch, power_supplies.sch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]
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2021-02-08 platform: r0.3: fix LED ordering, and add convenience ports
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2021-03-09 hardware: update host/sideband CC signals
    - add CC series resistors for reliable detection as sink when unpowered
    - add PD capacitors
    - update silkscreen to r0.3+
    [clock_pmod.sch, fpga_configuration.sch, host_side.sch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]
2021-03-10 hardware: update target CC signals
    - add PD output driver
    - add Rp (source mode) switch
    - add CC test points for all Type-C ports
    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
    [clock_pmod.sch, fpga_configuration.sch, host_side.sch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]
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2021-03-10 hardware: add ability to power board via J10
    - add diode to take 5 V input from J10 (Tag-Connect) pin 6
    - add TC2030-CTX as an alternative part for J10
    - move reset trace away from board edge
    - minor track and via adjustments
    [fpga_configuration.sch, luna_rev0.kicad_pcb]
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2021-03-10 hardware: set solder mask expansion to 0.05 mm
    [luna_rev0.kicad_pcb]
2021-04-20 gateware.transfer: Fix corner case causing a potential lockup for short packets.
    A packet is complete either when it has reached the max packet size or the last flag is set.
    We need to check both.
    Fixes #105
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2021-05-02 gateware.usb2: Fix OUT flow control.
    We need to allow data into the FIFO as long as there’s room, but discard
    the packet if the FIFO overflows.
2021-05-22 Correct the luna USB PID in the uacess udev rules.
2021-06-03 gateware.platform: fix issues with programming boards
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2021-08-19 gateware.usb2: USBInTransferManager - toggle DATA pid when sending ZLP
    Previously the pid was not toggled because it was tied to buffer
    swapping and we stay on the same buffer when sending a ZLP.
    This separates the buffer toggle & the pid value signals, and fixes the
    missing pid toggle on sending a ZLP.
    fixes #127
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2021-10-01 gateware.usb2: Fix filtering in USBTokenDetector.
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2021-10-18 Explicitly close the debugger after querying the device to prevent errors on Windows
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2022-01-08 Only load get_appropriate_platform when required
    This avoids a dependency to amaranth_boards if not using any
    pre-defined boards.
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2022-02-23 serdes_phy.backends.ecp5: fix Rterm settings for Diamond toolchain.
    [ecp5.py]
2022-03-04 serdes_phy.backends.ecp5: reset wrapped SerDes if requested.
    [ecp5.py]
2022-03-04 serdes_phy.backends.ecp5: replace TX GPIO interface with LFPS generator.
    [ecp5.py]
2022-03-10 serdes_phy.backends.ecp5: use correct encoding for CRD+ comma.
    [ecp5.py]
2022-03-17 serdes_phy.datapath: handle valid signaling correctly in Rx gearbox.
2022-03-17 serdes_phy.datapath: handle ready signaling correctly in Tx gearbox.
2022-03-17 serdes_phy.datapath: fix a CDC issue in Tx gearbox.
2022-03-17 serdes_phy.backends.ecp5: use Lattice-recommended reset sequencing.
    [ecp5.py]
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2022-03-17 serdes_phy.backends.ecp5: remove broken or unused in PIPE ports.
    [ecp5.py]
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2022-03-18 gateware.usb2: fix packet drop during overflow in USBStreamOutEndpoint
    Previously there was a corner case when the fifo becomes full at the exact same
    clock cycle than we are receiving the last byte of the USB packet.
    This caused to both ACK the packet and discard it from the fifo at the
    next clock cycle, resulting in a packet drop.
    Make sure we do not ACK the packet when the fifo is full.
    fixes #161
2022-03-25 usb3.physical.lfps: reset cycle counter when not generating bursts.
    [lfps.py]
2022-05-04 gateware.platform.ecpix5: comment out unused serdes pins to avoid nextpnr error
    If the pins are referenced but not actually used in the design, nextpnr will throw an error like this:
    ERROR: IO pin 'serdes_0__refclk__p$tr_io' constrained to pin 'AF12', which does not exist for package 'CABGA554'
2022-05-04 gateware.usb3.physical.lfps: fix LFPSGeneratorTest
    We need to bring `generate` low again, otherwise the generator will continue
    forever and never lower `drive_electrical_idle`.
    [lfps.py]
2022-06-08 Jenkins CI (#169)
    * jenkins: initial commit
    * jenkins: add tcl installation to dockerfile prerequsisites section
    * jenkins: add tcl-dev installation to dockerfile prerequsisites section
    * jenkins: use oss-cad-suite nightly build instead of building their tools from scratch
    * jenkins: fix typo
    * jenkins: add missing dependency to Dockerfile
    * jenkins: update PATH for installed pip tools
    * jenkins: poetry debugging
    * jenkins: more poetry debugging
    * jenkins: more poetry debugging 2
    * jenkins: more poetry debugging 3
    * jenkins: more poetry debugging 4
    * jenkins: add oss-cad-suite to PATH
    * jenkins: start using python3-venv for permissions reasons
    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
2023-01-04 hardware: update 3D model paths for KiCad 6
    see: https://gitlab.com/kicad/code/kicad/-/issues/10674
    [clock_pmod.kicad_sch, fpga_configuration.kicad_sch, host_side.kicad_sch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]
2023-01-10 hardware: add new footprint for D9
    This footprint is based on the manufacturer's recommendation rather than
    using a generic 0402 footprint. The 3D model is approximately correct.
    [fpga_configuration.kicad_sch, luna_rev0.kicad_pcb, luna_rev0.kicad_sch]
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2023-03-01 gateware.test.usb2: switch to in-tree USBPacketID
    Avoid using 2 different definitions of USBPacketID.
2023-03-30 gateware.usb: fix pending interrupts for USBDeviceController and eptri fifo peripherals
    Interrupts were being triggered correctly for these peripherals but
    the CSR pending register failed to show entries for the pending
    peripheral, instead returning a zero mask.
    This was due to upstream changes in lambdasoc EventSource which causes
    event definitions to be created by default with a mode of "level".
    There are three different supported modes:
    level: notification is raised when stb is high
    rise: notification is raised on rising edge of stb
    fall: notification is raised on falling edge of stb
    Setting the mode to "rise" on events for these peripherals resolves
    the problem.
    Other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
2023-05-09 platforms: update Cynthion pin assignments
    PMOD A and MEZZANINE pins were swapped in r0.7
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2023-09-28 gateware: do not use Pin as a value
    Pin.eq() shall be avoided. Use internal signals instead.
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2024-02-15 gateware.interface.psram: fix register read test case
2024-03-12 gateware: fix pin assignments and remove deprecated `Case()`
2024-03-12 gateware.usb2: improve/fix retrieval of bus name for USB device hooks
    Fixes name retrieval in new amaranth versions and fails silently
    when the bus name is not available.
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2024-05-18 Fixes for Microsoft OS 1.0 descriptor request handler.
    - Handler must only claim requests with its specified request code.
    - Recipient must be device for index 4, and interface for index 5.
    - Don't generate stalls - that's handled by not claiming requests.
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2024-06-06 examples: fix acm_serial example
    [acm.py]
2024-06-07 gateware.usb2: reset current speed, operating mode and termination select on exiting forced disconnect
2024-06-07 gateware.cdc: fix an order-of-operations bug with synchronize where output signals would not be skipped if they were of Pin type
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2024-06-08 gateware.usb.request.standard: pass max packet size to GetDescriptor handler
    Previously, enumeration would fail on a low-speed device as it would try
    to return a longer packet that allowed to GetDescriptor requests.
    This makes sure to pass the max packet size through to the handler to
    set the limit correctly.
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2025-01-28 Replace uses of `reset=` with `init=`
    [ecp5.py, i2c.py]
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
